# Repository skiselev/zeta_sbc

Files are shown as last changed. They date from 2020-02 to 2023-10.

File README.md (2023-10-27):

## Introduction

Zeta SBC V2 is a redesigned version of [Zeta SBC](http://www.malinov.com/Home/sergeys-projects/zeta-sbc). Compared to the first version this version features updated MMU with four banks, each one of those banks can be mapped to any 16 KiB page in 1 MiB on-board memory. It adds Z80 CTC which is used for generating periodic interrupts and as a vectored interrupt controller for UART and PPI. The FDC is replaced with 37C65. Compared to FDC9266 used in Zeta SBC it integrates input/output buffers and floppy disk control latch. Additionally 37C65 FDC is easier to obtain than FDC9266. And lastly it is made using CMOS technology and more power efficient than FDC9266

## Pictures

### Complete Board

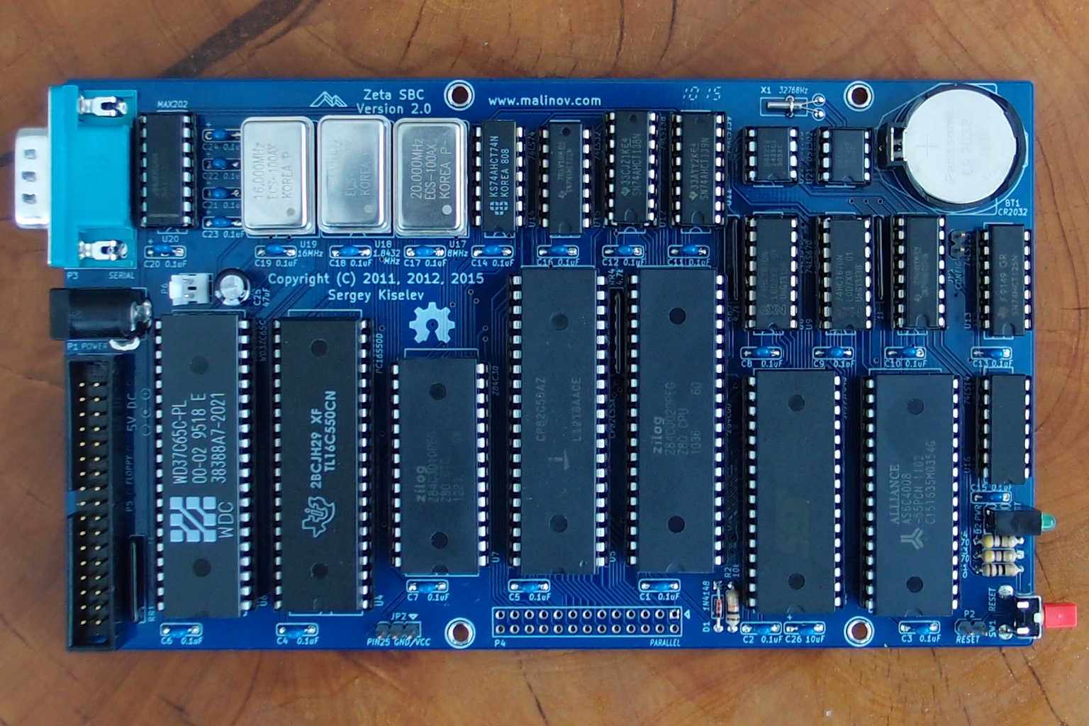
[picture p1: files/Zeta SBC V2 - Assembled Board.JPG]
Zeta SBC V2 - Assembled Board


### Zeta SBC with ParPortProp and a Floppy Drive

(FIXME: Picture shows Zeta SBC V1. Replace with Zeta SBC V2 when available.)
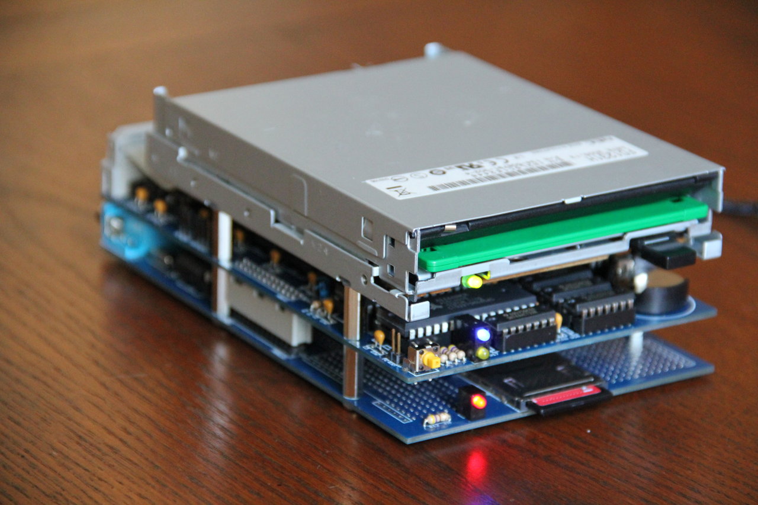
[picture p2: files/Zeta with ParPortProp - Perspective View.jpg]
Zeta SBC with ParPortProp


# Specifications

Zeta SBC V2 features following components:

* Z80 CPU
* 16550 UART - for connecting a console
* 8255 PPI - can be used for attaching a ParPortProp board, a hard drive using PPIDE or controlling some external devices
* Z80 CTC - can be used to generate periodic interrupts, and as an interrupt controller for UART and PPI
* Western Digital WD37C65, SMC FDC37C65, or GoldStar GM82C765B floppy disk controller.
* 512 KiB of battery backed SRAM
* 512 KiB of flash memory
* RTC

Zeta SBC V2 is compact and easy to build:

* Footprint of an 3.5" floppy drive (100 mm x 170.18 mm) and PCB can be mounted under a 3.5" drive.
* Uses only through hole components.
* Assumes using commonly available 3.5" floppy drives (not many people have 5.25" drives and even less 8" ones). Although it should work with 5.25" drives too.
* Only 2 configuration jumpers.
* Easy to use flash memory instead of UV EPROM.
* PCB mounted connectors, no need to build cables.
* Uses widely available components
* An easy way to get a "taste" of CP/M era computing.

# Hardware Documentation

File downloads are at the bottom of this page.

## KiCad Design Files

[Zeta SBC V2 - KiCad - 2.0.zip](files/Zeta%20SBC%20V2%20-%20KiCad%20-%202.0.zip)

## Schematic

[Zeta SBC V2 - Schematic - Color - 2.0.pdf](files/Zeta%20SBC%20V2%20-%20Schematic%20-%20Color%20-%202.0.pdf)

### PCB Version 2.0

[Zeta SBC V2 - Board - Color - 2.0.pdf](files/Zeta%20SBC%20V2%20-%20Board%20-%20Color%20-%202.0.pdf)

[Zeta SBC V2 - Gerber - 2.0.zip](files/Zeta%20SBC%20V2%20-%20Gerber%20-%202.0.zip)

## Input/Output Ports

* 20h - 23h (aliases 24h - 27h) - CTC Registers
  - 20h: Channel 0
  - 21h: Channel 1
  - 22h: Channel 2
  - 23h: Channel 3
  - See **Interrupts** section for Zeta SBC V2 specific CTC implementation and programming notes
* 28h (aliases 29h - 2Fh) - FDC CCR Register
  - Write only
  - FIXME: Add detailed description
* 30h (aliases 32h, 34h, 36h) - FDC Main Status Register
* 31h (aliases 33h, 35h, 37h) - FDC Data Register
* 38h (aliases 39h - 3Fh)
  - Write - FDC Diginal Output Register (DOR), also known as latch.
    + FIXME: Add detailed description
  - Read - Pulse FDC's /DACK and TC control lines
    + This port should be read following FDC data transfer command (read, write, format, etc.) to properly terminate data transfer.
* 60h-63h (alias 64h-67h) - PPI Registers
* 68h-6Fh - UART Registers
* 70h (aliases 71h-77h) - RTC Registers
  - Write:
    + Bits 0-3 - unused
    + Bit 4 - RTC Chip Enable
    + Bit 5 - RTC Write Enable
    + Bit 6 - RTC Clock
    + Bit 7 - RTC Input
  - Read:
    + Bit 0 - RTC Output
    + Bits 1-5 - unused
    + Bit 6 - Configuration Jumper (JP1)
    + Bit 7 - Disk Changed (DC) output from floppy drive. This can be used by the OS to detect floppy disk change. In such case CP/M should be warm rebooted.
* 78h-7Bh (alias 7Ch-7Fh) - Memory page select registers.
  - Write only
  - 78h - MPGSEL_0 - Page select register for bank #0 (0000h - 3FFFh)
  - 79h - MPGSEL_1 - Page select register for bank #1 (4000h - 7FFFh)
  - 7Ah - MPGSEL_2 - Page select register for bank #2 (8000h - 0BFFFh)
  - 7Bh - MPGSEL_3 - Page select register for bank #3 (0C000h - 0FFFFh)
  - Note: While these registers implemented as 8-bit registers, only 7 lower bits are decoded on board. 6 of these are actually used by on board memory, which contains of 64 pages, 16 KiB each.
* 7Ch (aliases 7Dh-7Fh) - MPGENA - Enable memory paging
  - Bits 0:
    + 0 = Disable memory paging (default after reset). When memory paging is disabled the memory page 0 (lower 16 KiB of the Flash ROM) is mapped to all banks.
    + 1 = Enable memory paging. Make sure that memory page select registers are configured properly before enabling paging.
  - Bits 1-7 - unused

## Memory

Zeta SBC V2 features a 512 KiB Flash ROM, and 512 KiB SRAM. The Flash ROM is used for the boot loader, monitor, OS (CP/M and ZSDOS at this point), and ROM disk. The SRAM is battery-backed, and is used for applications and for a RAM disk.

### Memory Banks and Paging

The 64 KiB Z80 memory address space is divided into four 16 KiB memory banks:

* Bank #0 (0000h - 3FFFh
* Bank #1 (4000h - 7FFFh)
* Bank #2 (8000h - 0BFFFh)
* Bank #3 (0C000h - 0FFFFh)

The physical memory (512 KiB Flash ROM and 512 KiB SRAM) is divided into 16 KiB pages:

* Pages 0 - 31 are mapped to the Flash ROM: page #0 starts at ROM address 00000h, and page #31 ends at ROM address 7FFFFh.
* Pages 32 - 63 are mapped to the SRAM: page #32 starts at RAM address 00000h, and page #63 ends at RAM address 7FFFFh.

Page select registers are used to map physical memory pages to the banks in Z80 address space:

* MPGSEL_0 (78h) - Page select register for bank #0
* M PGSEL_1 (79h) - Page select register for bank #1
* M PGSEL_2 (7Ah) - Page select register for bank #2
* M PGSEL_3 (7Bh) - Page select register for bank #3

Following a power on or a hard reset the memory paging mechanism is disabled, and memory address lines MA19 - MA14 are pulled down. So that page #0 (ROM addresses 00000h to 03FFF) is mapped to all four banks. That page should contain a boot loader that (among other things) configures and enables memory paging. Once page select registers are configured properly the memory paging can be enabled by setting bit 1 of MPGENA (7Ch) register.

### Programming Notes

1. The content of page select registers is unknown after a power on or a reboot. These registers need to be initialized before enabling memory paging. During the initialization the page select register for bank #0 needs to be set to page #0. So that CPU continues to execute instructions from that page.
2. The page select registers are implemented as 8-bit registers. Only 7 lower bits are decoded by Zeta SBC V2 memory chip select logic, and only 6 lower bits are actually used to address the memory. For future compatibility it is recommended that two higher bits of page select registers will be set to

## Interrupts

Zeta SBC V2 uses CTC as the source of vectored interrupts. For interrupts to function properly Z80 needs to be set to **interrupt mode 2**.

* Channels 0 and 1 are chained together. So that channel 1 can be used to generate low-frequency periodic interrupts:
  - Channel's 0 CLK/TG input is connected to UART_CLK/2 signal (921.6 kHz frequency)
  - Channel's 1 CLK/TG input in connected to c hannel's 0 ZC/TO output
* Channels 2 and 3 are connected to UART and FDC interrupt outputs. They can be used to generate vectored interrupts for these controllers:
  - Channel's 2 CLK/TG input is connected to UART interrupt output
  - Channel's 3 CLK/TG input is connected to 8255 PPI port PC3. This port is used as the interrupt output in PPI modes 1 and 2.

### Programming CTC to Generate Periodic Interrupts

CTC can generate periodic interrupts by dividing CTC clock (921.6 kHz) using channels 0 and 1 configured in counter mode. The CTC clock is connected to the trigger input of channel 0, and the ZC (zero count) output of channel 0 is connected the trigger input of channel 1. So that channel 0 will divide the clock, and the resulting signal will be divided further using channel 1.

In this example channel 0 is programmed with time constant of 256, so it will divide the input clock by 256, resulting in 3.6 kHz pulses. The channel 1 is programmed with down counter of 240, and will divide 3.6 kHz clock by 240, resulting in 15 Hz signal. That channel is also programmed to generate an interrupt every time counter reaches 0.

* Output `01000111 `to the channel 0. Configure the channel in the counter mode.
* Output `00000000&#xA0;`to the channel 0. Set the time constant to 256.
* Output `11000111 `to the channel 1. Configure the channel in the counter mode and enable interrupt when counter reaches 0.
* Output `11110000` to the channel 1. Set the time constant to 240, so that the interrupt will be generated every 1/15 of a second.
* Output `VVVVV000&#xA0;`to the channel 0. Set bits 7-3 of the interrupt vector. Bits 15-8 are set to the value of I register, bits 2 and 1 are set to the CTC channel number that caused the interrupt. Bit 0 is always 0. Note that each interrupt vector takes 2 bytes of memory and it should start on an even address.

### Programming CTC as an Interrupt Controller

CTC can be used as interrupt controller for UART and 8255 PPI using channels 2 and 3 respectively. In this case a CTC channel needs to be programmed for counter mode operation with time constant of 1. So that the first transition on CLK/TG input will result in counter going to 0 and CTC generating an interrupt.

* Output `110L0111` to the selected channel. This configures the channel in the counter mode with interrupts enabled. Bit 4 (L) sets the triggering edge: 0 - falling edge; 1 - rising edge.
* Output `00000001` to the selected channel. This loads value 1 to the time constant, so that an interrupt will be generated after detecting the first edge on the trigger input.
* Output `VVVVV000&#xA0;`to the channel 0. This sets bits 7-3 of the interrupt vector. Bits 15-8 are set to the I register, bits 2 and 1 are set to the CTC channel number that caused the interrupt. Bit 0 is always 0. Note that each interrupt vector takes 2 bytes of memory and it should start on an even address.

## Real Time Clock

Zeta SBC V2 includes a Maxim DS1302 RTC chip for timekeeping. It uses a CR2032 battery for power backup. The DS1302 has a 3-wire serial interface, and it is programmed through the RTC register (70h) using bit-banging. See Input/Output Ports section for the RTC register description. Please refer to [DS1302 datasheet](http://datasheets.maximintegrated.com/en/ds/DS1302.pdf) for programming information, and to the RomWBW (dsrtc.asm) for an RTC interface implementation.

## Jumpers and Connectors

### Jumper JP1 - CONFIG

JP1 is a software configuration jumper. It can be read by software using RTC port (70h) bit 6. This jumper is used by the RomWBW firmware with the ParPortProp support to configure the console device: it will use UART when this jumper is installed, and ParPortProp / VGA terminal when the jumper is not installed.

### Jumper JP2 - PIN25_GND/VCC

JP2 connects pin 25 of the parallel port P4 to either GND or Vcc (+5). Note that pin 1 is the pin that is closer to the parallel connector.

Warning: If JP2 is set incorrectly, it is possible to create a short circuit of the 5 Volt power supply.

| **Jumper Position** | **Description** |
| :--- | :--- |
| 1-2 | P4 pin 25 is connected to the ground |
| 2-3 | P4 pin 25 is connected to Vcc. Use this position with PPIDE, make sure to set jumper K1 on PPIDE to position 2-3. Please refer to [PPIDE documentation](https://sites.google.com/w/file/28373213/ppide-Install.txt) for more information. |
| **no jumper*** | P4 pin 25 is left open |

\* default

### Connector P1 - POWER

Connect regulated +5V power supply to this connector.

| Pin | Description |
| :-- | :--- |
| tip (the inner contact) | Positive terminal - +5V |
| barrel / sleeve | Negative terminal - ground |

### Connector P2 - RESET

P2 is a connector for an external reset button.

### Connector P3 - SERIAL

P3 is the serial port connector. It is normally used for connecting a console or terminal. P3 uses pinout similar to that of IBM AT serial port (with some signals missing). Use a null modem cable to connect to a PC.

| **Pin Number** | **Signal Name** | **Description and Notes** |
| :--- | :--- | :--- |
| 1 | DCD | Carrier Detect; Not used - Not connected on the SBC |
| **2** | **RX** | **Receive Data; Input to SBC** |
| **3** | **TX** | **Transmit Data; Output from SBC** |
| 4 | DTR | Data Terminal Ready;Not used - Not connected on the SBC |
| **5** | **Signal Ground** | **Connected to the SBC GND signal** |
| 6 | DSR | Data Set Ready;Not used - Not connected on the SBC |
| **7** | **RTS** | **Request to Send; Output from SBC** |
| **8** | **CTS** | **Clear to Send; Input to SBC** |
| 9 | RI | Ring Indicator;Not used - Not connected on the SBC |
| **Shield** | **DE9 Shield** | **Connected to the SBC GND signal** |

### Connector P4 - PARALLEL

P4 is the parallel port connector. It is connected directly to the 8255 PPI and can be used for attaching, a ParPortProp board, an IDE hard disk using the PPIDE mini board, or for controlling external devices (e.g. printer, watering system), or for extending the SBC (e.g. connecting an LCD display and a keyboard). The pinout of P4 is the same as in other N8VEM boards (SBC V1, SBC V2, SBC-188).

| **Pin Number** | **Description** | **Pin Number** | **Description** | **Pin Number** | **Description** | **Pin Number** | **Description** |
| :--- | :--- | :--- | :--- | :--- | :--- | :--- | :--- |
| 1 | PC0 | 9 | PC4 | 17 | PB7 | 25 | GND or VCC (see JP2) |
| 2 | PA0 | 10 | PA4 | 18 | PB0 | 26 | GND |
| 3 | PC1 | 11 | PC5 | 19 | PB6 |  |  |
| 4 | PA1 | 12 | PA5 | 20 | PB1 |  |  |
| 5 | PC2 | 13 | PC6 | 21 | PB5 |  |  |
| 6 | PA2 | 14 | PA6 | 22 | PB2 |  |  |
| 7 | PC3 | 15 | PC7 | 23 | PB4 |  |  |
| 8 | PA3 | 16 | PA7 | 24 | PB3 |  |  |

### Connector P5 - FLOPPY

P5 is the floppy interface connector. It uses PC compatible pinout. When using a PC floppy cable with a twist, Drive A (ID 0) is the drive after the twist and Drive B (ID 1) is the drive before the twist. When using only one FDD, either a twisted cable can be used, or the BIOS can be patched to use Drive B.

| **Pin Number** | **Description** | **Direction (relative to the SBC)** | **Connected to** |
| :--- | :--- | :--- | :--- |
| 1-33 | Odd pins are GND |  | GND |
| 2 | High Density. This signal is ignored by most (all?) 3.5" drives. | Output | DOR (bit 6) |
| 4, 6 | Not used |  | No connection |
| 8 | Index Pulse | Input | Schmidt Trigger, FDC (IDX) |
| 10 | Motor On B | Output | DOR (bit 1), Buffer |
| 12 | Drive Select A | Output | FDC (US0, US1), Decoder |
| 14 | Drive Select B | Output | FDC (US0, US1), Decoder |
| 16 | Motor On A | Output | DOR (bit 1), Buffer |
| 18 | Direction | Output | FDC (LCT/DIR), Multiplexer |
| 20 | Step | Output | FDC (FR/STEP), Multiplexer |
| 22 | Write Data | Output | FDC (WDOUT), OC Buffer |
| 24 | Write Enable | Output | FDC (WE), OC Buffer |
| 26 | Track Zero | Input | Multiplexer, FDC (FLT/TR0) |
| 28 | Write Protect | Input | Multiplexer, FDC (WP/TS) |
| 30 | Read Data | Input | Schmidt Trigger, FDC (~DSKD) |
| 32 | Select Head | Output | FDC (HD), OC Buffer |
| 34 | Disk Changed | Input | DIR (bit 0) |

### Connector P6 - 5V

P6 is the 5V power output for the floppy drive. Alternatively it can be used instead of P1 for supplying power to the board. It is recommended to use a polarized header for P6 to avoid incorrect power polarity which probably will destroy FDD or components on the SBC board.

| **Pin Number** | **Description** |
| :--- | :--- |
| 1 | 5V |
| 2 | GND |

**Warning P6 connector's key is reversed compared to Zeta SBC V 1.x. Please pay attention when upgrading from older boards. The polarity marking on the silkscreen is correct.**

## Bill of Materials (BOM)

### BOM Notes

Disclaimer: I did my best to make sure that components listed in this BOM will be compatible with Zeta SBC V2. Obviously I didn't order all of components listed here, and I was not able to actually verify that they will work. Please make sure to double check specifications on manufacturer's and seller's web site before ordering. Please let me know if you found any problems or incompatibilities.

Many components have multiple part numbers listed in BOM. There are some differences between various part numbers, such as:

* Different manufacturer. For example Texas Instruments vs. National Semiconductor for IC. Usually ICs built using the same technology will be 100% compatible. For some other components, for example connectors, sockets, or capacitors, it could be some difference in the quality. It is likely to get a better quality connector from TE (was AMP/Tyco) than from some obscure manufacturer (e.g. components sold under Jameco ValuePro brand).
* Specification differences
  - IC built using different different technologies (CMOS, TTL, NMOS) will have different specifications, and you might prefer to use certain IC family.
  - Difference in IC frequency or speed rating, especially for CPU, PPI, and memory.
  - Mechanical differences, especially for switches. Pick whatever suits best in your enclosure.
  - Some other minor differences. For example: RoHS or Pb-free vs. regular components; thickness of gold plating on connectors; frequency stability of oscillators and crystals.
* Price differences
  - For some reason some components are priced much higher than other otherwise similar parts.
  - One extreme example would be 512 KiB SRAM chips sold by Jameco (157358 and 242448) for almost $19 each, while AS6C4008-55PCN part sold by Mouser costs less than $5.
  - Some eBay sellers ask premium price for components because of their perceived uniqueness (keywords: vintage, rare, NOS, collectible), or special packaging (e.g. pink ceramic vs. plastic, gold plating).

If unsure what to order, read specifications on seller's and manufacturer's web sites. Also please read Replacement Notes below. Finally, consult people on [N8VEM news group](http://groups.google.com/group/n8vem).

## BOM

| **Component type** | **Reference** | **Description** | **Quantity** | **Possible sources and notes** |
| :--- | :--- | :--- | :--- | :--- |
| PCB |  | Zeta SBC V2 PCB Version 2.0 | 1 | Order from Sergey |
| Battery Holder | BT1 | CR2032 batter holder, 20 mm lead spacing | 1 | Mouser [122-2420-GR](http://www.mouser.com/ProductDetail/Eagle-Plastic-Devices/122-2420-GR/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 "Click to view additional information on this product."),[122-2620-GR](http://www.mouser.com/ProductDetail/Eagle-Plastic-Devices/122-2620-GR/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 "Click to view additional information on this product.");Jameco [355434](http://www.jameco.com/webapp/wcs/stores/servlet/Product_10001_10001_355434_-1) |
| Capacitor | C1 - C24 | 0.1 uF ceramic, 5.08 mm lead spacing | 24 | Mouser [810-FK28X7R1H104K](http://www.mouser.com/search/refine.aspx?Keyword=810-FK28X7R1H104K),[80-C323C104K5R](http://www.mouser.com/ProductDetail/Kemet/C323C104K5R5TA/?qs=sGAEpiMZZMuAYrNc52CMZJc2YQhHPlYVWR1uyzMGvKQ%3D); Jameco [25523](http://www.jameco.com/webapp/wcs/stores/servlet/Product_10001_10001_25523_-1) |
| Capacitor | C25 | 47 uF, 6.3 V electrolytic | 1 | Mouser [667-ECA-1HHG470](http://www.mouser.com/ProductDetail/Panasonic-Electronic-Components/ECA-1HHG470/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 "Click to view additional information on this product.");Jameco [31114](http://www.jameco.com/webapp/wcs/stores/servlet/Product_10001_10001_31114_-1) |
| Capacitor | C26 | 10 uF ceramic, 5.08 mm lead spacing | 1 | Mouser [810-FK24X5R1C106K](http://www.mouser.com/search/refine.aspx?Keyword=810-FK24X5R1C106K) Note: Can be replaced with tantalum or electrolytic capacitors |
| Diode | D1 | 1N4148 | 1 | Mouser [512-1N4148](http://www.mouser.com/ProductDetail/Fairchild-Semiconductor/1N4148/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 "Click to view additional information on this product."),[771-1N4148-T/R](http://www.mouser.com/ProductDetail/NXP-Semiconductors/1N4148113/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 "Click to view additional information on this product.");Jameco [36038](http://www.jameco.com/webapp/wcs/stores/servlet/Product_10001_10001_36038_-1),[179215](http://www.jameco.com/webapp/wcs/stores/servlet/Product_10001_10001_179215_-1) |
| Diode | D2, D3 | Bi-level LED indicator | 1 | Mouser [696-SSF-LXH240GYD](http://www.mouser.com/ProductDetail/Lumex/SSF-LXH240GYD/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 "Click to view additional information on this product."); Jameco: Search for uni-color bi-level LED |
| Standoff | HOLE1, HOLE2, HOLE3, HOLE4 | Standoff, M3 male / female, 20 mm | 4 | Mouser [534-24317](http://www.mouser.com/ProductDetail/Keystone-Electronics/24317/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 "Click to view additional information on this product."),[534-25505](http://www.mouser.com/ProductDetail/Keystone-Electronics/25505/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 "Click to view additional information on this product."),[855-R30-3012002](http://www.mouser.com/ProductDetail/Harwin/R30-3012002/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 "Click to view additional information on this product.") Note: The length of male end of these standoffs is 8 mm. It is too long for some floppy disk drives (you'll notice that standoff doesn't go completely inside the floppy drive mount hole). In this case cut a few millimeters using a file or a fine saw. |
| Screw | HOLE1, HOLE2, HOLE3, HOLE4 | Screw, M3, 6 mm | 4 | Use regular 3 mm floppy or CD-ROM drive mounting screws. Mouser [534-29311](http://www.mouser.com/ProductDetail/Keystone-Electronics/29311/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) |
| Connector | JP1, P2 | 2x1 pin header | 2 | Mouser [649-78229-102HLF](http://www.mouser.com/ProductDetail/FCI/78229-102HLF/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 "Click to view additional information on this product.");Jameco [108338](http://www.jameco.com/webapp/wcs/stores/servlet/Product_10001_10001_108338_-1) |
| Connector | JP2 | 3x1 pin header | 1 | Mouser [649-69190-103HLF](http://www.mouser.com/ProductDetail/FCI/69190-103HLF/?qs=sGAEpiMZZMvlX3nhDDO4AIYfP1TbgJhjYISz3bCP%2Fwo%3D "Click to view additional information on this product."),[649-78229-103HLF](http://www.mouser.com/ProductDetail/FCI/78229-103HLF/?qs=sGAEpiMZZMtsLRyDR9nM14Vjyw4ze%252bjtWzL%2FZN0BySE%3D "Click to view additional information on this product.");Jameco [109576](http://www.jameco.com/webapp/wcs/stores/servlet/Product_10001_10001_109576_-1) |
| Connector | P1 | DC jack | 1 | Mouser [806-KLDX-0202-A](http://www.mouser.com/ProductDetail/Kycon/KLDX-0202-A/?qs=sGAEpiMZZMu2f9RNbWupYrp4fVeNia8SgJaG%252bI5Hr1k%3D "Click to view additional information on this product.");Jameco [101178](http://www.jameco.com/webapp/wcs/stores/servlet/Product_10001_10001_101178_-1) |
| Connector | P3 | DE9M, right angle PCB mount | 1 | Mouser [806-K22X-E9P-N](http://www.mouser.com/ProductDetail/Kycon/K22X-E9P-N/?qs=sGAEpiMZZMu857ZbtCGHt0PbUrjjd%2FNBm0naypBlx9c%3D "Click to view additional information on this product."),[806-K22X-E9P-N-99](http://www.mouser.com/ProductDetail/Kycon/K22X-E9P-N-99/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 "Click to view additional information on this product.") (teal color),[571-7478404](http://www.mouser.com/ProductDetail/TE-Connectivity-AMP/747840-4/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 "Click to view additional information on this product.");Jameco [104943](http://www.jameco.com/webapp/wcs/stores/servlet/Product_10001_10001_104943_-1),[614459](http://www.jameco.com/webapp/wcs/stores/servlet/Product_10001_10001_614459_-1),[614432](http://www.jameco.com/webapp/wcs/stores/servlet/Product_10001_10001_614432_-1); |
| Connector | P4 | 13x2 pin header | 1 | Mouser [649-68602-126HLF](http://www.mouser.com/ProductDetail/FCI/68602-126HLF/?qs=sGAEpiMZZMtsLRyDR9nM1%252bmbmmVUI0dAYWKlImNZbew%3D),[649-77313-824-26LF](http://www.mouser.com/ProductDetail/FCI/77313-824-26LF/?qs=sGAEpiMZZMtsLRyDR9nM14Vjyw4ze%252bjtilYVPfgiHws%3D);Jameco [53495](http://www.jameco.com/webapp/wcs/stores/servlet/Product_10001_10001_53495_-1) Note: don't use shrouded connector, as it will interfere with the standoff and other components. |
| Connector | P5 | 17x2 pin header shrouded | 1 | Mouser [517-30334-6002](http://www.mouser.com/ProductDetail/3M-Electronic-Solutions-Division/30334-6002HB/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 "Click to view additional information on this product."),[571-1033087](http://www.mouser.com/ProductDetail/TE-Connectivity/103308-7/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 "Click to view additional information on this product."),[571-5103308-7](http://www.mouser.com/ProductDetail/TE-Connectivity/5103308-7/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 "Click to view additional information on this product.");Jameco [68583](http://www.jameco.com/webapp/wcs/stores/servlet/Product_10001_10001_68583_-1),[753547](http://www.jameco.com/webapp/wcs/stores/servlet/Product_10001_10001_753547_-1) |
| Connector | P6 | 2 pin header with friction lock | 1 | Mouser [571-6404562](http://www.mouser.com/ProductDetail/TE-Connectivity-AMP/640456-2/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),[571-3-641126-2](http://www.mouser.com/ProductDetail/TE-Connectivity-AMP/3-641126-2/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),[571-3-641215-2](http://www.mouser.com/ProductDetail/TE-Connectivity-AMP/3-641215-2/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);Jameco [232266](http://www.jameco.com/webapp/wcs/stores/servlet/Product_10001_10001_232266_-1),[613931](http://www.jameco.com/webapp/wcs/stores/servlet/Product_10001_10001_613931_-1); Corresponding female connector: Mouser [571-770602-2](http://www.mouser.com/ProductDetail/TE-Connectivity-AMP/770602-2/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);Jameco [234798](http://www.jameco.com/webapp/wcs/stores/servlet/Product_10001_10001_234798_-1)Contacts (2 contacts needed):Mouser [571-770666-1](http://www.mouser.com/ProductDetail/TE-Connectivity-AMP/770666-1/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);Jameco [234923](http://www.jameco.com/webapp/wcs/stores/servlet/Product_10001_10001_234923_-1),[736501](http://www.jameco.com/webapp/wcs/stores/servlet/Product_10001_10001_736501_-1); It is recommended to use a polarized header to avoid incorrect power polarity. |
| Resistor | R1 | 10 Ohm, 1/4 W | 1 | Mouser [291-10-RC](http://www.mouser.com/ProductDetail/Xicon/291-10-RC/?qs=sGAEpiMZZMu61qfTUdNhG5WVxMYmJR0O1OUR1xbHmxs%3D);Jameco [690380](http://www.jameco.com/webapp/wcs/stores/servlet/Product_10001_10001_690380_-1) |
| Resistor | R2 | 10 kOhm, 1/4 W | 1 | Mouser [291-10K-RC](http://www.mouser.com/ProductDetail/Xicon/291-10K-RC/?qs=sGAEpiMZZMu61qfTUdNhG6xwTrVwTvbz8PPav3aExs8%3D); Jameco [691104](http://www.jameco.com/webapp/wcs/stores/servlet/Product_10001_10001_691104_-1) |
| Resistor | R3, R4 | 470 Ohm, 1/4 W | 2 | Mouser [291-470-RC](http://www.mouser.com/ProductDetail/Xicon/291-470-RC/?qs=sGAEpiMZZMu61qfTUdNhG1AdbDi3ermZfsjMZ8nKiDY%3D); Jameco [690785](http://www.jameco.com/webapp/wcs/stores/servlet/Product_10001_10001_690785_-1) |
| Resistor Array | RR1, RR2 | 1 kOhm, 6 pin, bussed resistor array | 2 | Mouser [264-1.0K-RC](http://www.mouser.com/ProductDetail/Xicon/264-10K-RC/?qs=sGAEpiMZZMvrmc6UYKmaNQbJ%252b29QTxaEngMB%2FdVaAdM%3D "Click to view additional information on this product."),[652-4306R-1LF-1K](http://www.mouser.com/ProductDetail/Bourns/4306R-101-102LF/?qs=sGAEpiMZZMvrmc6UYKmaNTNUNwWuH088chgRi4yNveI%3D "Click to view additional information on this product.") Note: When using CMOS U11, RR2 can have a higher value, for example 4.7k. This will reduce the power consumption. |
| Resistor Array | RR3, RR4 | 4.7 kOhm, 6 pin, bussed resistor array | 2 | Mouser [264-4.7K-RC](http://www.mouser.com/ProductDetail/Xicon/264-47K-RC/?qs=sGAEpiMZZMvrmc6UYKmaNVNDE5UWkgN%2FsgYW0PIGqes%3D "Click to view additional information on this product."),[652-4306R-1LF-4.7K](http://www.mouser.com/ProductDetail/Bourns/4306R-101-472LF/?qs=sGAEpiMZZMvrmc6UYKmaNWgIZ6biHU4EEgaZTof5r6w%3D "Click to view additional information on this product.") |
| Switch | SW1 | Tactile switch, right angle | 1 | Mouser [653-B3F-3100](http://www.mouser.com/ProductDetail/Omron-Electronics/B3F-3100/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 "Click to view additional information on this product."),[653-B3F-3152](http://www.mouser.com/ProductDetail/Omron-Electronics/B3F-3152/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 "Click to view additional information on this product."),[706-95C06A2RAT](http://www.mouser.com/ProductDetail/Grayhill/95C06A2RAT/?qs=sGAEpiMZZMsgGjVA3toVBGztKQtvElzogNtUxy25yuk%3d "Click to view additional information on this product."),[706-95C06C2RAT](http://www.mouser.com/ProductDetail/Grayhill/95C06C2RAT/?qs=sGAEpiMZZMsgGjVA3toVBGztKQtvElzoxqE4Q1H5TNc%3d "Click to view additional information on this product."),[706-95C06F2RAT](http://www.mouser.com/ProductDetail/Grayhill/95C06F2RAT/?qs=sGAEpiMZZMsgGjVA3toVBGztKQtvElzoEUXifV0kpgg%3d "Click to view additional information on this product.")Note: Switches can have different actuator length. You might want to select the switch according your own preferences, for example the enclosure type you want to use, and whatever you want the reset button to stick out of the enclosure or to stay hidden inside. Jameco [1953575](http://www.jameco.com/webapp/wcs/stores/servlet/Product_10001_10001_1953575_-1) |
| IC | U1 | Z80 CPU, CMOS, 40 pin DIP - Z84C00xxPEG | 1 | Mouser [692-Z84C0010PEG](http://www.mouser.com/ProductDetail/ZiLOG/Z84C0010PEG/?qs=sGAEpiMZZMvu0Nwh4cA1wSoSQ2enekUq2IMsKtAiEbo%3D),[692-Z84C0008PEG](http://www.mouser.com/ProductDetail/ZiLOG/Z84C0008PEG/?qs=sGAEpiMZZMvu0Nwh4cA1wWtRoPcQBaz3A%252bL%2FQ9ovAB8%3D); Jameco [35705](http://www.jameco.com/webapp/wcs/stores/servlet/Product_10001_10001_35705_-1),[35781](http://www.jameco.com/webapp/wcs/stores/servlet/Product_10001_10001_35781_-135781) Frequency of U17 (CPU clock) oscillator should be less or equal to CPU frequency. 8MHz CPU recommended for 1.44 MB floppy disks support. |
| IC | U2 | 512 KiB flash, 32 pin DIP - 39SF040,29F040, 29C040 | 1 | Mouser [804-39SF0407CPHE](http://www.mouser.com/ProductDetail/Microchip-Technology/SST39SF040-70-4C-PHE/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 "Click to view additional information on this product."); Jameco [242667](http://www.jameco.com/webapp/wcs/stores/servlet/Product_10001_10001_242667_-1) |
| IC | U3 | 512 KiB SRAM, 32 pin DIP -AS6C4008-55PCN | 1 | Mouser [913-AS6C4008-55PCN](http://www.mouser.com/ProductDetail/Alliance-Memory/AS6C4008-55PCN/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) Note: Jameco 242448 and 157358 (BS62LV4006P) should work too, but they are way too expensive |
| IC | U4 | 16550 UART | 1 | Mouser [926-PC16550DN/NOPB](http://www.mouser.com/ProductDetail/Texas-Instruments/PC16550DN-NOPB/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); Jameco [288809](http://www.jameco.com/webapp/wcs/stores/servlet/Product_10001_10001_288809_-1) |
| IC | U5 | 8255 PPI | 1 | Mouser [968-CP82C55AZ](http://www.mouser.com/ProductDetail/Intersil/CP82C55AZ/?qs=cbl4%252bYHJGOF3%2FjEgaAvGRe5K%2FILMXjQ3),[968-CP82C55A](http://www.mouser.com/ProductDetail/Intersil/CP82C55A/?qs=B4b5rvZIvWUoKcRPBZOAqTe8YvZ7Q5In); Jameco [52417](http://www.jameco.com/webapp/wcs/stores/servlet/Product_10001_10001_52417_-1) Unicorn Electronics (order 82C55) |
| IC | U6 | FDC, 40 pin DIP WD37C65, FDC37C65, GM82C765 | 1 | Buy from eBay |
| IC | U7 | Z80 CTC, CMOS, 28 pin DIP -Z84C30xxPEG | 1 | Mouser [692-Z84C3010PEG](http://www.mouser.com/ProductDetail/ZiLOG/Z84C3010PEG/?qs=sGAEpiMZZMtp5ziQ9mm%252bAlDnLybnUSNF),[692-Z84C3008PEG](http://www.mouser.com/ProductDetail/ZiLOG/Z84C3008PEG/?qs=sGAEpiMZZMsn4IaorHFpML59rb7vgZ39); Jameco [35609](http://www.jameco.com/webapp/wcs/stores/servlet/Product_10001_10001_35609_-1) |
| IC | U8, U9 | 74LS670 | 2 | Mouser [595-SN74LS670N](http://www.mouser.com/search/refine.aspx?Keyword=595-SN74LS670N),[771-HCT670N652](http://www.mouser.com/search/refine.aspx?Keyword=771-HCT670N652); Jameco [47976](http://www.jameco.com/webapp/wcs/stores/servlet/Product_10001_10001_47976_-1) Unicorn Electronics 74LS670 |
| IC | U10 | 74LS174 | 1 | Mouser [595-SN74ALS174N](http://www.mouser.com/ProductDetail/Texas-Instruments/SN74ALS174N/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),[595-SN74LS174N](http://www.mouser.com/ProductDetail/Texas-Instruments/SN74LS174N/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),[595-SN74AHCT174N](http://www.mouser.com/ProductDetail/Texas-Instruments/SN74AHCT174N/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); Unicorn Electronics; Jameco [46931](http://www.jameco.com/webapp/wcs/stores/servlet/Product_10001_10001_46931_-1) |
| IC | U11 | 74ALS139 | 1 | Mouser [595-SN74ALS139N](http://www.mouser.com/ProductDetail/Texas-Instruments/SN74ALS139N/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),[595-SN74LS139AN](http://www.mouser.com/ProductDetail/Texas-Instruments/SN74LS139AN/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),[595-CD74ACT139E](http://www.mouser.com/ProductDetail/Texas-Instruments/CD74ACT139E/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),[595-SN74AHCT139N](http://www.mouser.com/ProductDetail/Texas-Instruments/SN74AHCT139N/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); Unicorn Electronics; Jameco [46623](http://www.jameco.com/webapp/wcs/stores/servlet/Product_10001_10001_46623_-1),[301268](http://www.jameco.com/webapp/wcs/stores/servlet/Product_10001_10001_301268_-1) |
| IC | U12 | 74LS138 | 1 | Mouser [595-SN74ALS138AN](http://www.mouser.com/ProductDetail/Texas-Instruments/SN74ALS138AN/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),[595-SN74LS138N](http://www.mouser.com/ProductDetail/Texas-Instruments/SN74LS138N/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),[595-SN74AHCT138N](http://www.mouser.com/ProductDetail/Texas-Instruments/SN74AHCT138N/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); Unicorn Electronics; Jameco [46607](http://www.jameco.com/webapp/wcs/stores/servlet/Product_10001_10001_46607_-1),[301233](http://www.jameco.com/webapp/wcs/stores/servlet/Product_10001_10001_301233_-1),[44927](http://www.jameco.com/webapp/wcs/stores/servlet/Product_10001_10001_44927_-1) |
| IC | U13 | 74LS125 | 1 | Mouser [595-SN74LS125AN](http://www.mouser.com/ProductDetail/Texas-Instruments/SN74LS125AN/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),[595-SN74AHCT125N](http://www.mouser.com/ProductDetail/Texas-Instruments/SN74AHCT125N/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); Unicorn Electronics; Jameco [46501](http://www.jameco.com/webapp/wcs/stores/servlet/Product_10001_10001_46501_-1) |
| IC | U14 | 74LS74 | 1 | Mouser [595-SN74ALS74AN](http://www.mouser.com/ProductDetail/Texas-Instruments/SN74ALS74AN/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),[595-SN74AHCT74N](http://www.mouser.com/search/refine.aspx?Keyword=595-SN74AHCT74N); Jameco [48004](http://www.jameco.com/webapp/wcs/stores/servlet/Product_10001_10001_48004_-1),[295726](http://www.jameco.com/webapp/wcs/stores/servlet/Product_10001_10001_295726_-1),[45137](http://www.jameco.com/webapp/wcs/stores/servlet/Product_10001_10001_45137_-1) Unicorn Electronics 74ALS74, 74AHCT74 |
| IC | U15 | 74LS32 | 1 | Mouser [595-SN74ALS32N](http://www.mouser.com/ProductDetail/Texas-Instruments/SN74ALS32N/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),[595-SN74LS32N](http://www.mouser.com/ProductDetail/Texas-Instruments/SN74LS32N/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),[595-SN74ACT32N](http://www.mouser.com/ProductDetail/Texas-Instruments/SN74ACT32N/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),[595-CD74ACT32E](http://www.mouser.com/ProductDetail/Texas-Instruments/CD74ACT32E/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); Unicorn Electronics; Jameco [47466](http://www.jameco.com/webapp/wcs/stores/servlet/Product_10001_10001_47466_-1),[295515](http://www.jameco.com/webapp/wcs/stores/servlet/Product_10001_10001_295515_-1) |
| IC | U16 | 74LS14 | 1 | Mouser [595-SN74LS14N](http://www.mouser.com/ProductDetail/Texas-Instruments/SN74LS14N/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),[595-SN74AHCT14N](http://www.mouser.com/ProductDetail/Texas-Instruments/SN74AHCT14N/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); Unicorn Electronics; Jameco [46640](http://www.jameco.com/webapp/wcs/stores/servlet/Product_10001_10001_46640_-1),[295460](http://www.jameco.com/webapp/wcs/stores/servlet/Product_10001_10001_295460_-1),[44935](http://www.jameco.com/webapp/wcs/stores/servlet/Product_10001_10001_44935_-1) |
| IC | U17 | CPU clock oscillator, full can | 1 | See frequency selection note for U1. 4 MHz: Mouser [815-ACO-4-EK](http://www.mouser.com/ProductDetail/ABRACON/ACO-4000MHZ-EK/?qs=sGAEpiMZZMt8zWNA7msRCufK6FojpZgBkZbpC3y2DKw%3D),[520-TCF400-X](http://www.mouser.com/ProductDetail/ECS/ECS-100AX-40/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);Jameco [27967](http://www.jameco.com/webapp/wcs/stores/servlet/Product_10001_10001_27967_-1) 6 MHz: Mouser [520-TCF600-X](http://www.mouser.com/ProductDetail/ECS/ECS-100AX-60/?qs=sGAEpiMZZMt8zWNA7msRCkZF6o3VgKlSVVceCglATlo%3D) 8 MHz: Mouser [815-ACO-8-EK](http://www.mouser.com/ProductDetail/ABRACON/ACO-8000MHZ-EK/?qs=sGAEpiMZZMt8zWNA7msRCufK6FojpZgBol2LWy2yIwI%3D),[520-TCF800-X](http://www.mouser.com/ProductDetail/ECS/ECS-100AX-80/?qs=sGAEpiMZZMt8zWNA7msRCkZF6o3VgKlSdZ7QUqFOCa0%3D);Jameco [27991](http://www.jameco.com/webapp/wcs/stores/servlet/Product_10001_10001_27991_-1) 10 MHz: Mouser [815-ACO-10-EK](http://www.mouser.com/ProductDetail/ABRACON/ACO-10000MHZ-EK/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),[520-TCF1000-X](http://www.mouser.com/ProductDetail/ECS/ECS-100AX-100/?qs=sGAEpiMZZMt8zWNA7msRCkZF6o3VgKlSWiBx3iH%252buXU%3D);Jameco [27887](http://www.jameco.com/webapp/wcs/stores/servlet/Product_10001_10001_27887_-1) 20 MHz: Mouser [815-ACO-20-EK](http://www.mouser.com/ProductDetail/ABRACON/ACO-20000MHZ-EK/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),[520-TCF2000-X](http://www.mouser.com/ProductDetail/ECS/ECS-100AX-200/?qs=sGAEpiMZZMt8zWNA7msRCkZF6o3VgKlSDgSisz37dM4%3D);Jameco [27932](http://www.jameco.com/webapp/wcs/stores/servlet/Product_10001_10001_27932_-1) |
| IC | U18 | 1.8432 MHz oscillator, full can | 1 | Mouser [520-TCF184-X](http://www.mouser.com/ProductDetail/ECS/ECS-100AX-18432/?qs=sGAEpiMZZMt8zWNA7msRCkZF6o3VgKlSBPpGLyq2pks%3D); Jameco [27879](http://www.jameco.com/webapp/wcs/stores/servlet/Product_10001_10001_27879_-1) |
| IC | U19 | 16 MHz oscillator, full can | 1 | Mouser [520-TCF1600-X](http://www.mouser.com/ProductDetail/ECS/ECS-100AX-160/?qs=sGAEpiMZZMt8zWNA7msRCkZF6o3VgKlScoRySUymIsQ%3d),[815-ACO-16-EK](http://www.mouser.com/ProductDetail/ABRACON/ACO-16000MHZ-EK/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) |
| IC | U20 | MAX202 | 1 | Mouser [595-TRS202ECN](http://www.mouser.com/ProductDetail/Texas-Instruments/TRS202ECN/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),[701-SP202ECP-L](http://www.mouser.com/ProductDetail/Exar/SP202ECP-L/?qs=sGAEpiMZZMtnIqnDeWcRHSgmUQC5j8NkoHNGApCEA9Y%3D),[700-MAX202CPE](http://www.mouser.com/ProductDetail/Maxim-Integrated-Products/MAX202CPE+/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),[700-MAX232ACP](http://www.mouser.com/ProductDetail/Maxim-Integrated-Products/MAX232ACPE+/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); Jameco [1800552](http://www.jameco.com/webapp/wcs/stores/servlet/Product_10001_10001_1800552_-1),[142535](http://www.jameco.com/webapp/wcs/stores/servlet/Product_10001_10001_142535_-1) |
| IC | U21 | DS1302 | 1 | Mouser [700-DS1302](http://www.mouser.com/ProductDetail/Maxim-Integrated-Products/DS1302+/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),[700-DS1302N](http://www.mouser.com/ProductDetail/Maxim-Integrated-Products/DS1302N+/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); Jameco [176778](http://www.jameco.com/webapp/wcs/stores/servlet/Product_10001_10001_176778_-1),[780481](http://www.jameco.com/webapp/wcs/stores/servlet/Product_10001_10001_780481_-1) |
| IC | U22 | DS1210 | 1 | Mouser [700-DS1210](http://www.mouser.com/ProductDetail/Maxim-Integrated-Products/DS1210+/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); Jameco [114198](http://www.jameco.com/webapp/wcs/stores/servlet/Product_10001_10001_114198_-1) |
| IC Socket | U1, U4 - U6 | 40 pin 600 mil DIP socket | 4 | Mouser [517-4840-6000-CP](http://www.mouser.com/ProductDetail/3M-Electronic-Solutions-Division/4840-6000-CP/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),[649-DILB40P223TLF](http://www.mouser.com/ProductDetail/FCI/DILB40P-223TLF/?qs=sGAEpiMZZMs%2FSh%2Fkjph1tnWBa37eU7kEvItX7WAak1Y%3D);Jameco [41111](http://www.jameco.com/webapp/wcs/stores/servlet/Product_10001_10001_41111_-1) |
| IC Socket | U2, U3 | 32 pin 600 mil DIP socket | 2 | Mouser [517-4832-6000-CP](http://www.mouser.com/ProductDetail/3M-Electronic-Solutions-Division/4832-6000-CP/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),[649-DILB32P223TL](http://www.mouser.com/ProductDetail/FCI/DILB32P223TLF/?qs=sGAEpiMZZMs%2FSh%2Fkjph1tuCWXqks4O6emg1jqvuxPfs%3D);Jameco [112301](http://www.jameco.com/webapp/wcs/stores/servlet/Product_10001_10001_112301_-1) |
| IC Socket | U7 | 28 pin 600 mil DIP socket | 1 | Mouser [517-4828-6000-CP](http://www.mouser.com/ProductDetail/3M-Electronic-Solutions-Division/4828-6000-CP/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),[649-DILB28P223TLF](http://www.mouser.com/ProductDetail/FCI/DILB28P-223TLF/?qs=sGAEpiMZZMs%2FSh%2Fkjph1tnWBa37eU7kELM2y4cpXfjk%3D) |
| IC Socket | U8 - U12, U24 | 16 pin 300 mil DIP socket | 6 | Mouser [517-4816-3000-CP](http://www.mouser.com/ProductDetail/3M-Electronic-Solutions-Division/4816-3000-CP/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),[649-DILB16P-223TLF](http://www.mouser.com/ProductDetail/FCI/DILB16P-223TLF/?qs=sGAEpiMZZMs%2FSh%2Fkjph1tnWBa37eU7kEZ8uy8DVlop0%3D);Jameco [37373](http://www.jameco.com/webapp/wcs/stores/servlet/Product_10001_10001_37373_-1) |
| IC Socket | U13 - U16 | 14 pin 300 mil DIP socket | 4 | Mouser [517-4814-3000-CP](http://www.mouser.com/ProductDetail/3M-Electronic-Solutions-Division/4814-3000-CP/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),[649-DILB14P-223TLF](http://www.mouser.com/ProductDetail/FCI/DILB14P-223TLF/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);Jameco [37162](http://www.jameco.com/webapp/wcs/stores/servlet/Product_10001_10001_37162_-1) |
| IC Socket | U21, U22 | 8 pin 300 mil DIP socket | 2 | Mouser [517-4808-3000-CP](http://www.mouser.com/ProductDetail/3M-Electronic-Solutions-Division/4808-3000-CP/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),[649-DILB8P223TLF](http://www.mouser.com/ProductDetail/FCI/DILB8P-223TLF/?qs=sGAEpiMZZMs%2FSh%2Fkjph1trsk3O0a2elqycTEeDCVfAg%3D);Jameco [51571](http://www.jameco.com/webapp/wcs/stores/servlet/Product_10001_10001_51571_-1) |
| Oscillator Socket | U17 - U19 | 4 pin 300 mil DIP full can oscillator socket | 3 | Mouser [535-1107741](http://www.mouser.com/ProductDetail/Aries/1107741/?qs=sGAEpiMZZMs%2FSh%2Fkjph1tvt1%2FmEPT%2FXoVZs6QxzSzII%3D);Jameco [133006](http://www.jameco.com/webapp/wcs/stores/servlet/Product_10001_10001_133006_-1) |
| Crystal | X1 | 32768 Hz crystal | 1 | Mouser [695-CFS206-327KB-U](http://www.mouser.com/ProductDetail/Citizen/CFS206-32768KDZB-UB/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),[520-ECS327-6-13-X](http://www.mouser.com/ProductDetail/ECS/ECS-327-6-13X/?qs=sGAEpiMZZMsBj6bBr9Q9aWDZfF25lWfigWLFR7cXhrY%3d),[628-VT200F-6PF20PPM](http://www.mouser.com/ProductDetail/Seiko-Semiconductors/VT200F-6PF20PPM/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);Jameco [14584](http://www.jameco.com/webapp/wcs/stores/servlet/Product_10001_10001_14584_-1) |

### Replacement Notes

* 74xx logic
  - TTL logic families: 74LS, 74ALS, 74F, or TTL-compatible CMOS: 74HCT, 74AHCT, and 74ACT could be used.
  - Plain 74LS should work with CPU frequency up to 8 MHz. But it is recommended to use higher speed and lower power 74ALS ICs.
  - (FIXME: NOT TESTED YET) Tested with 74LS, 74ALS and 74HCT / 74AHCT logic families. Works on frequency up to 20MHz.
* Z80 CPU, Z80 CTC
  - Either NMOS or CMOS parts work. It is recommended to use at least 4 MHz CPU. 6 MHz or faster CPU is required for 1.44MB disk support. 8 MHz is recommended.
  - CMOS versions - Z84C00xxPEG or Z84C00xxPEC, and Z84C30xxPEG or Z84C30xxPEC are recommended.
  - Note: PEG or PEC suffixes mean 40 pin plastic DIP package, PEG is RoHS compliant, PEC is not.
  - Tested with CMOS Z84C00 (6MHz, 8MHz, 20MHz) and NMOS Z8400 (4MHz) CPUs, and CMOS Z84C0010PEG CTC
* 16550 UART
  - 16550 UART is recommended. 8250 or 16450 UARTs can be used as well, but they don't have FIFO.
  - Tested with: Texas Instruments TL16C550, Exar ST16C550, National Semiconductor NS16550AFN, California Micro Devices CM16C550, Goldstar GM16C450, and UMC 8250B
* 8255 PPI
  - It is recommended to use higher speed CMOS versions. For example 8 MHz Intersil / Harris CP82C55A part (note CP82C55A-5 is 5 MHz), 10 MHz Toshiba TMP82C55AP-10 or NEC D71055C-10 parts.
  - Tested with: Harris/Intersil CP82C55, TMP82C55AP-10, NEC D71055C-10, Intel 8255-5
* MAX202
  - Can be replaced by pin compatible devices like Maxim MAX232A, Texas Instruments TRS202, or Analog Devices ADM202, that use 0.1uF capacitors for charge pumps.
  - It is possible to use MAX232 or other parts that need 1uF capacitors. In this case capacitors C21 - C24 have to be replaced with 1uF capacitors. Pay attention to capacitors' polarity if using electrolytic capacitors.
* Bi-Level LED Indicator
  - Can be replaced by two 3 mm LEDs with pins bent at 90 degrees.
* Oscillators
  - It is possible to use half can oscillators instead of full can oscillators. In this case install oscillator at pins 4 - 11 . Refer to the PCB silkscreen for oscillator placement.

## Power Supply

Zeta SBC V2 requires a **regulated** 5V power supply. Make sure that the tip of the power supply is the positive lead. System's power consumption varies depending on components used on SBC (CMOS CPU/PPI/UART vs. NMOS components, CMOS logic vs. TTL/LS vs. TTL/ALS) and CPU clock frequency. Also floppy disk drives are relatively power hungry (about 1 A max). Jameco carries quite a few regulated switching 5V wall adapters with different amperage. See these catalog pages:

[http://www.jameco.com/Jameco/catalogs/c113/P105.pdf](http://www.jameco.com/Jameco/catalogs/c113/P105.pdf)

[http://www.jameco.com/Jameco/catalogs/c113/P106.pdf](http://www.jameco.com/Jameco/catalogs/c113/P106.pdf)

Alternatively it is possible to use a linear power supply with 7805 or similar voltage regulator (make sure to use a heatsink, especially if powering a floppy drive).

# Mods

Mods described here were intentionally not implemented on PCB to keep it simple.

* It is possible to use FTDI DB9-USB-M module (Mouser [895-DB9-USB-RS232-M](http://www.mouser.com/ProductDetail/FTDI/DB9-USB-M/?qs=sGAEpiMZZMtcidiSkZ6c9v%252b4CMhdZ6iS)) instead of the serial port connector P3. This module contains RS232 to USB converter IC and provides a mini USB connector. (Alexey, thank you for this tip). It even might be possible to use FTDI DB9-USB-D5-M module, eliminating MAX232A and related capacitors, and connecting the module directly to the UART.
* If you don't plan to use 8255 PPI, it can be omitted. In this case it is not needed to install U5, C5, P4, and JP2.
* It is possible to build Zeta SBC V2 without floppy disk controller (for example for the test purposes, or if you don't need floppy). In this case following components can be omitted: U6, U19, C6, C19, RR1, P5, P6.
* It is possible to build system without RTC, in this case following components can be omitted: U21, X1
* If you don't want battery backup for SRAM, it is possible to omit U22 and BT1. In this case it is needed to connect U22 pin 5 to pin 6 (~RAM_CS) and pin 1 to pin 8 (VCC).

# PCB Versions

## PCB Version 2.0 (Changes from Zeta SBC 1.3)

* Major schematic and PCB change. Board rerouted, most of ICs moved around or shifted.
* Added Z80 CTC
* Replaced FDC9266 floppy disk controller and related discrete logic with WD37C65
* New memory banking implementation.
* Serial port uses RTS/CTS for flow control instead of DSR/DTS.

## Various Ideas

* Image enhancements
  - NVRAM support (BIOS configuration using NVRAM), NVRAM configuration utility
* Enhance utility for programming the BIOS, CP/M, and ROM disk separately. (It already supports the full image programming)
* Add incorrect power supply polarity protection
  - Option 1: Schottky diode in series
  - Option 2: Diode connected in parallel to power supply, in reverse (could be dangerous if power supply is not short circuit protected)
  - Option 3: Use FET

# Files

| Link | Modified |
| :--- | :--- |
| [Zeta SBC V2 - Assembled Board.JPG](files/Zeta%20SBC%20V2%20-%20Assembled%20Board.JPG) (853k) | Sergey Kiselev, Mar 30, 2015, 9:11 AM |
| [Zeta SBC V2 - Board - Color - 2.0.pdf](files/Zeta%20SBC%20V2%20-%20Board%20-%20Color%20-%202.0.pdf) (1200k) | Sergey Kiselev, Jun 15, 2015, 10:48 AM |
| [Zeta SBC V2 - Gerber - 2.0.zip](files/Zeta%20SBC%20V2%20-%20Gerber%20-%202.0.zip) (260k) | Sergey Kiselev, Jun 15, 2015, 10:47 AM |
| [Zeta SBC V2 - KiCad - 2.0.zip](files/Zeta%20SBC%20V2%20-%20KiCad%20-%202.0.zip) (457k) | Sergey Kiselev, Jun 15, 2015, 10:47 AM |
| [Zeta SBC V2 - Schematic - Color - 2.0.pdf](files/Zeta%20SBC%20V2%20-%20Schematic%20-%20Color%20-%202.0.pdf) (210k) | Sergey Kiselev, Jun 15, 2015, 10:48 AM |
| [Zeta with ParPortProp - Perspective View.jpg](files/Zeta%20with%20ParPortProp%20-%20Perspective%20View.jpg) (190k) | Sergey Kiselev, Jan 23, 2015, 11:40 AM |

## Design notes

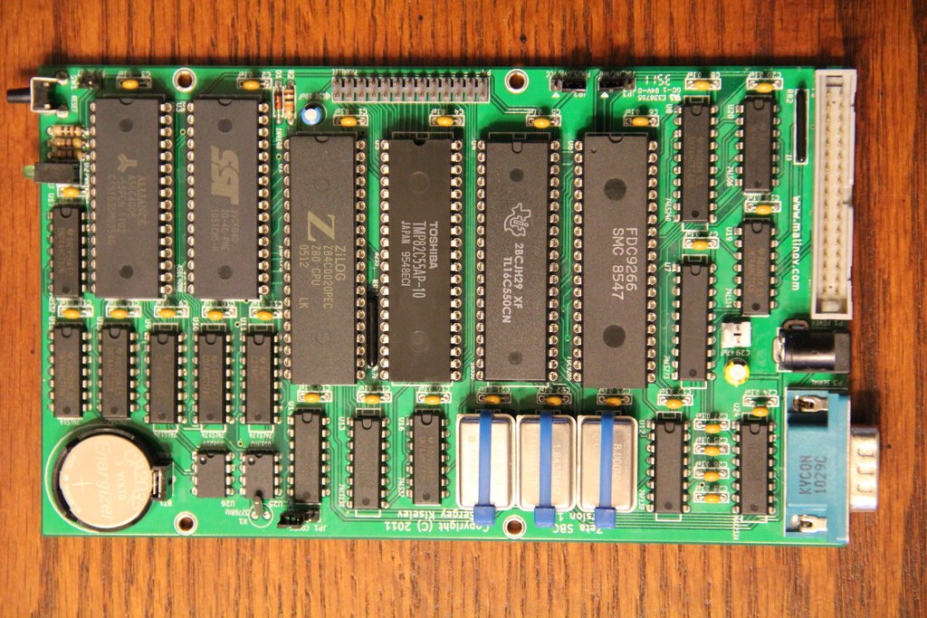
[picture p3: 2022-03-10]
files/Zeta Board.jpg

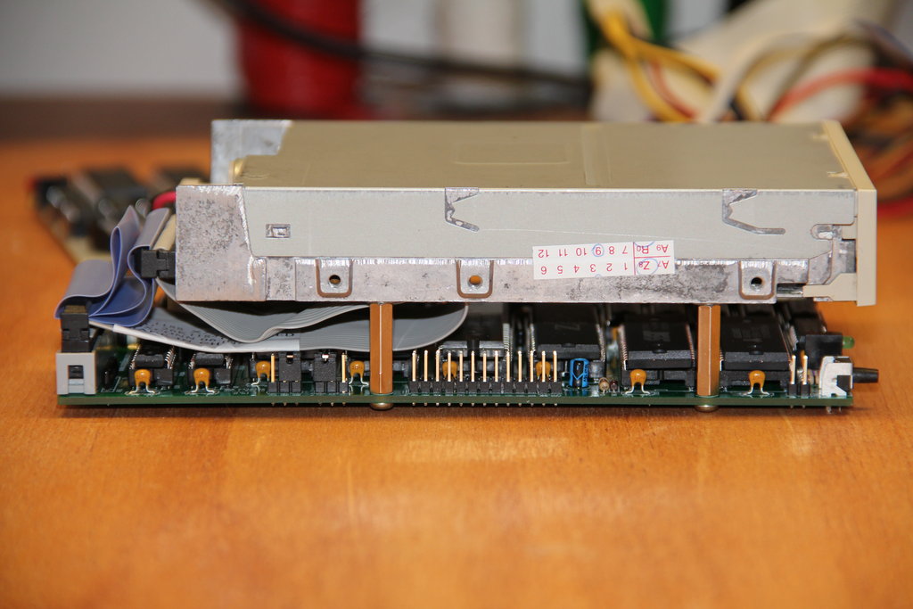
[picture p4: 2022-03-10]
files/Complete System.jpg

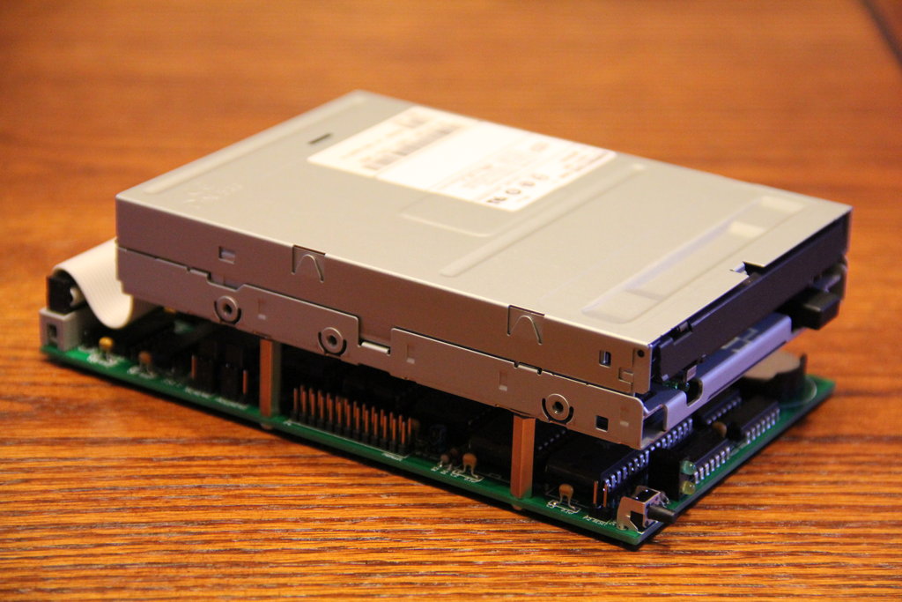
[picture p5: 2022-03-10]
files/Complete System - Perspective View.jpg

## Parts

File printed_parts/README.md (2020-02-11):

# Zeta SBC
3D Printable Enclosure for Zeta SBC and ParPortProp Based System

## Description
This is a 3D printable enclosure for Zeta SBC. This design is inspired by [OpenSCAD Parametric Box by FB Aka Heartman/Hearty](http://heartygfx.blogspot.com).
I did a complete redesign to support the specific requirements I had for the Zeta SBC based system.

This enclosure fits a Zeta SBC or Zeta SBC V2 SBC with a ParPortProp board mounted under it, and a 3.5" floppy drive mounted on top of it.

I've included two front panel designs: The [first one](Zeta-Front-Floppy_with_Bezel.stl) works with regular floppy drives that
have their own bezel. The [second one](Zeta-Front-Floppy_no_Bezel_Sony.stl) works with the Sony MPF920-L drive without bezel.
It is assumed that for the Reset button Zeta SBC uses a tactile switch with the projected plunger and a 4 x 4 mm key top.
Refer to [Recommended Electronic and Hardware Parts](#recommended-electronic-and-hardware-parts) section below for the part numbers.

The boards and the floppy drive are mounted together using eight 15 mm standoffs.
The board stack is then mounted to the bottom of the enclosure using 4 flat head M3 x 12 mm screws that go into the standoffs.
The top part and the bottom parts are secured together using 4 flat head M3 x 8 mm screws going into threaded mounting holes
on the sides of the floppy drive, and 2 flat head M3 x 6 mm screws and 2 sqare nuts placed into the slots in the bottom part.

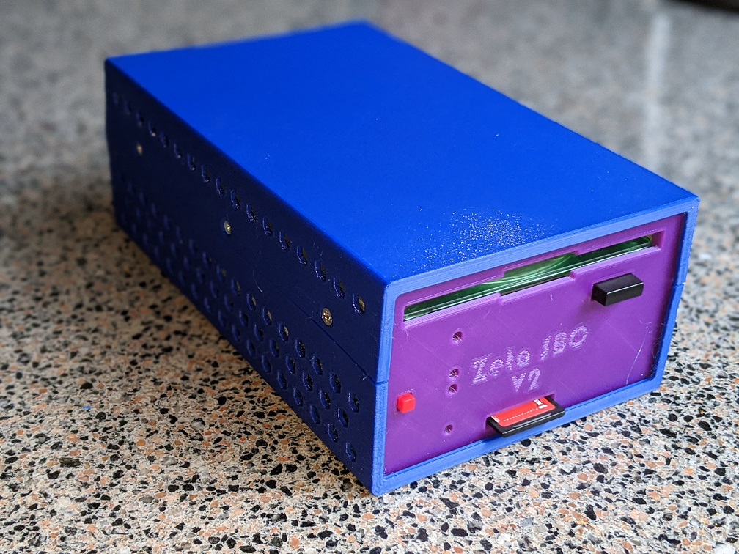
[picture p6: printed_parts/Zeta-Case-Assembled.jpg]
Zeta SBC Case - Assembled


## 3D Printed Parts

* [Enclosure Bottom](Zeta-Bottom.stl)
* [Enclosure Back](Zeta-Back.stl)
* [Enclosure Front with Floppy Drive Cutout](Zeta-Front-Floppy_with_Bezel.stl)
* [Enclosure Front for Sony MPF920-L drive without bezel](Zeta-Front-Floppy_no_Bezel_Sony.stl)
* [Enclosure Top](Zeta-Top.stl)
* [OpenSCAD Source Code](CaseGenerator-Zeta.scad)

### 3D Printing Recommendations

Print these parts with the "flat face" down. Use the "Rotate" function in your slicer software to rotate parts accordingly.
The front and the back parts should be printed with the outer side facing the printer bed.
Make sure to clean any 3D printing artifacts prior to assembling the case.
Use a 3.2 mm (1/8") drill bit to clean the M3 holes in the top and bottom parts.

## Recommended Electronic and Hardware Parts

Part Name      | Description                      | Quantity | Part Number
-------------- | -------------------------------- | -------- | ------------------
Tactile Switch | Right Angle, Projected Plunger   | 1        | Mouser [653-B3F-3152](https://www.mouser.com/ProductDetail/653-B3F-3152)
Key Top        | 4 mm x 4 mm, Red                 | 1        | Mouser [653-B32-1080](https://www.mouser.com/ProductDetail/653-B32-1080)
Standoff       | M3 x 15 mm, Hex, OD: 5 mm, Male/Female | 8  | Mouser [534-24315](https://www.mouser.com/ProductDetail/534-24315)
Screw          | M3 x 12 mm, Hex Drive Flat Socket Cap | 4   | Fastenal [M42510012A40000](https://www.fastenal.com/products/details/M42510012A40000)
Screw          | M3 x 8 mm, Hex Drive Flat Socket Cap | 4    | Fastenal [M42510008A40000](https://www.fastenal.com/products/details/M42510008A40000)
Screw          | M3 x 6 mm, Hex Drive Flat Socket Cap | 2    | Fastenal [M42510006A40000](https://www.fastenal.com/products/details/M42510006A40000)
Nut            | M3 x 1.8 mm, Square Nut          | 2        | Fastenal [0161907](https://www.fastenal.com/products/details/0161907)

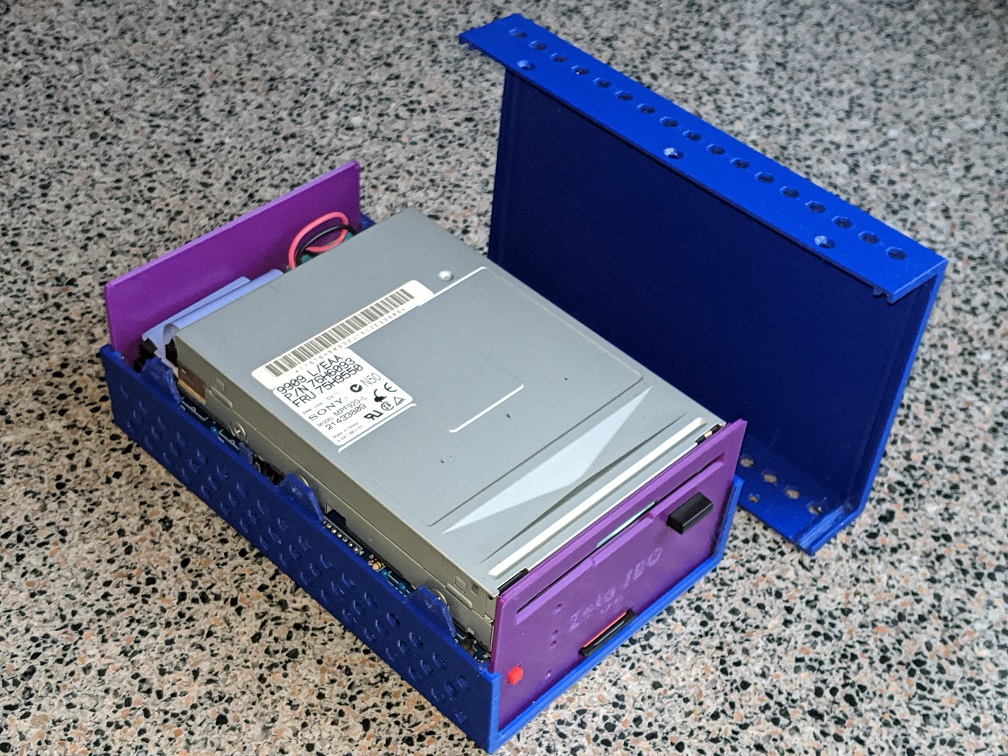
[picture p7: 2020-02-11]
printed_parts/Zeta-Case-Open.jpg

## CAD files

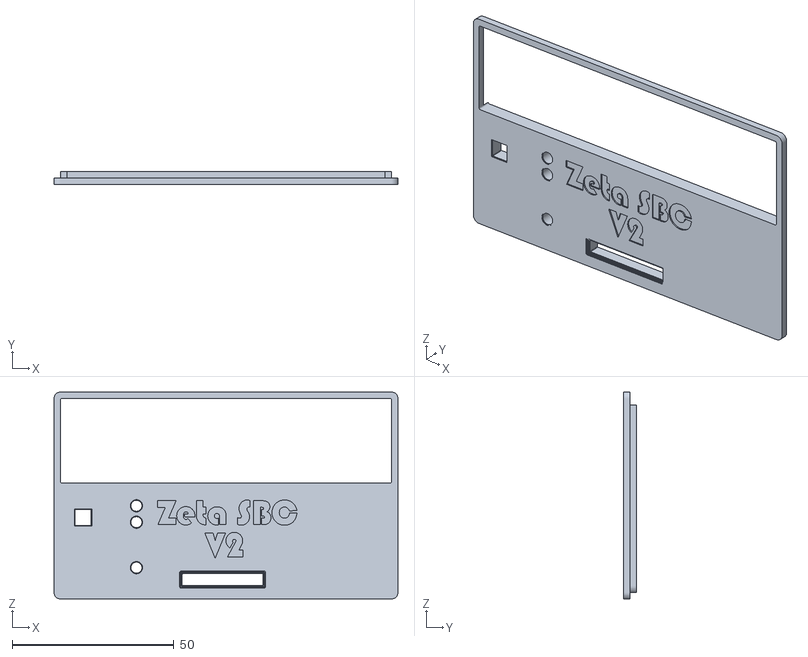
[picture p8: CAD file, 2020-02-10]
printed_parts/Zeta-Front-Floppy_with_Bezel.stl
106.4 x 4.00 x 64.0

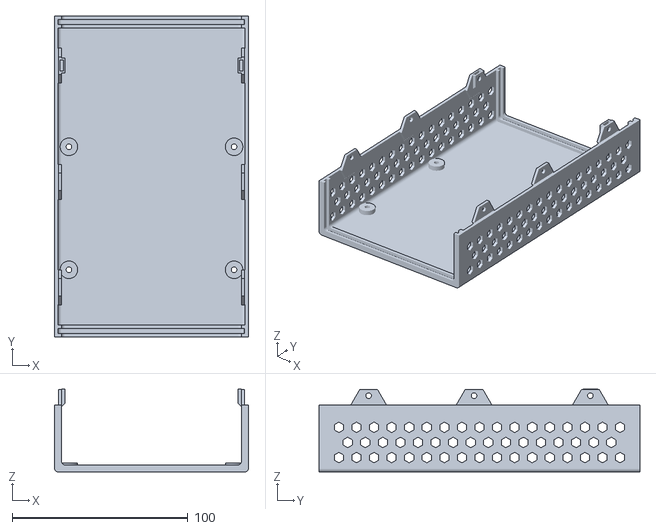
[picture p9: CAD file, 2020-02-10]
printed_parts/Zeta-Bottom.stl
110.4 x 182.6 x 47.2

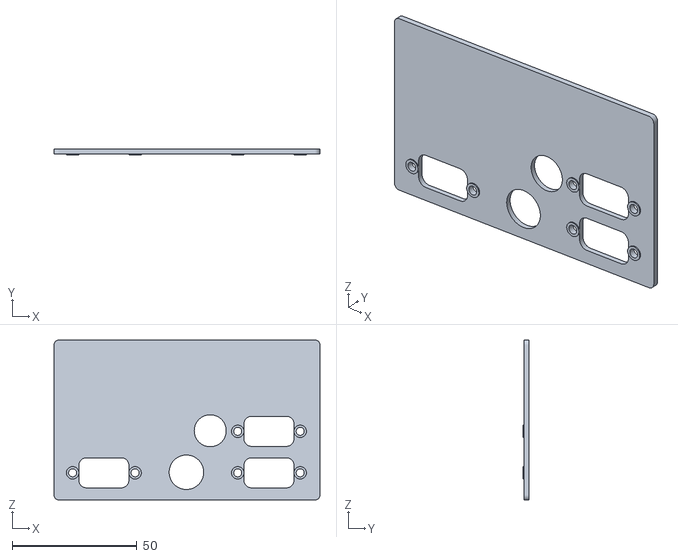
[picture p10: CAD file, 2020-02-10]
printed_parts/Zeta-Back.stl
106.4 x 2.40 x 64.0

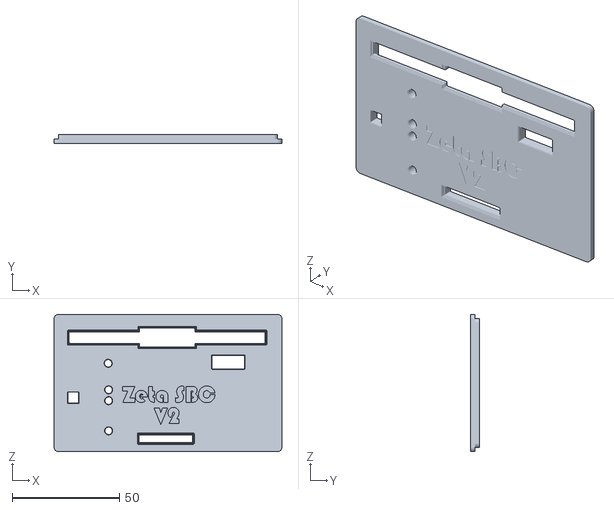
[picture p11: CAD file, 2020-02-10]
printed_parts/Zeta-Front-Floppy_no_Bezel_Sony.stl
106.4 x 4.00 x 64.0

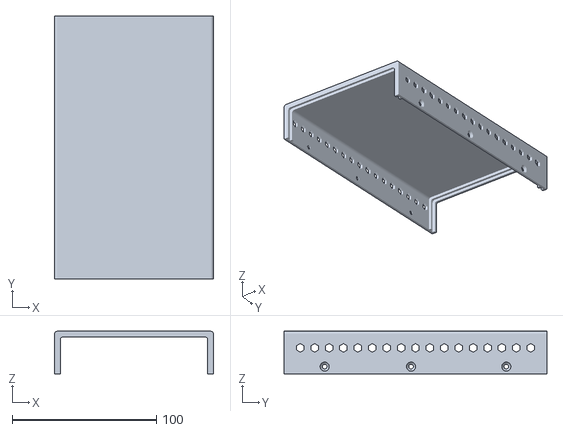
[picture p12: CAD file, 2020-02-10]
printed_parts/Zeta-Top.stl
110.4 x 182.6 x 29.6

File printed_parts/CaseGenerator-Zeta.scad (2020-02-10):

////////////////////////////////////////////////////////////////////////////////
// Parametric Case Generator for Electronic Projects
// Copyright (C) 2020 Sergey Kiselev
// 
// Inspired by FB Aka Heartman/Hearty 2016 OpenScad Parametric Box
// http://heartygfx.blogspot.com
////////////////////////////////////////////////////////////////////////////////

////////////////////////////////////////////////////////////////////////////////
// Notes:
// The case dimensions are the internal dimensions. The external dimensions
//   are automatically calculated based on the internal dimensions, the wall
//   thickness, and the PCB supports height. The internal height does not include
//   the height of the PCB standoffs
// The origin for the top and the bottom of the case
//   is left/front/bottom of the PCB
// The origin for the front panel is left/0/bottom of the PCB
// The origin for the back panel is right/0/bottom of the PCB. It is mirrored
//   relative to the front panel, so that it can be printed with the face down

// Rendering control. Set respective value to 1 to render the part, or to 0 to
//   skip rendering
top = 1;
bottom = 1;
front = 1;
back = 1;
vent = 1; // Render ventilation holes
standoffs = 0; // Render PCB standoffs
// Project specific - Zeta SBC. Set to 1 to render the front panel with
// a large rectangular cutout for the floppy drive. Set to 0 to render the front
// panel to be used with the Sony MPF920L floppy drive without bezel.
floppy_bezel = 0;

// Project-specific settings
pcb_thick = 1.6;
board_spacing = 15; // distance between two boards (standoffs length)

// Inside dimensions of the case
length = 172.18; // the actual board length 170.18 + front_thick-thick
width = 101.6;
height = (pcb_thick+board_spacing)*2+25.4;
// Middle - indicates the height at which the top/bottom connecting screws
//   are placed
middle = (pcb_thick+board_spacing)*2+5;

// Parameters
// Tolerance - added to the internal dimensions and also to the slots width for
//   the front and the back panels
xy = 0.4; // tolerance for X/Y
z = 0.2; // tolerance for Z
// Resolution for the cylinder shapes (holes, case corners).
//   Indicates the number of rectangular segments per cylinder
r = 60;
// Wall thickness
thick = 2;
// Front panel thickness
front_thick = 4;
// Back panel thickness
back_thick = 2;
// Radius of the corners for the top and the bottom
corner_radius = 2;
// Diameter of the ventilation holes
vent_diameter = 6;
// Spacing of the ventilation holes
vent_y_spacing = 10;
vent_z_spacing = 8.6;
// Standoffs height from the inner side of the bottom of the case to the 
//   bottom of the PCB. To ensure proper front panel fit, it is recommended
//   that the standoffs height would be more than or equal to wall thickenss
standoff_height = 3;
// Standoffs outer diameter
standoff_diameter = 10;
// Ear parameters
// Location (Y/depth) of the mounting ears (relative to the board front)
// and hex nut slot - 0 = no hex nut slot, 1 = hex nut slot
// Zeta - removed two middle ears, and add slot for a hex nut for the back ear?
//ear_params = [[21,0], [21+60,0], [21+90,0], [length-21,1]];
ear_params = [[23,0], [23+60,0], [length-23,1]];
// Standoff parameters 
// Location X,Y relative to front left corner of the PCB
standoff_params = [[(width-94)/2,(front_thick-thick)+31],[(width-94)/2,(front_thick-thick)+31+70],[width-(width-94)/2,(front_thick-thick)+31],[width-(width-94)/2,(front_thick-thick)+31+70]];
// Holes diameter
hole_diameter = 3.2;
// Screw head diameter
head_diameter = 6+xy;
// Mounting ears radius
ears_radius = 10;
// The height of the mounting holes in the ears, relative to the middle line
hole_height = 5;
// Nut slot inside dimensions
nut_width = 5.5;
nut_thick = 1.6;
// Nut slot outside dimensions - Width of the nut slot across corners
nut_slot_width = 8.6;
nut_slot_height = 7.6;
// Top / bottom color
color1 = "Orange";
// Panels color
color2 = "OrangeRed";

// Dimensions calculations
// External width - walls thickness added two times, once for the
//   actual wall, another one for the hinge/connector
ext_width = width+thick*4+xy*2;
// External length - tolernace is added 6 times, twice for each panel slot
//   and once for the tolerance between the wall and the PCB
ext_length = length+thick*4+xy*6;
// External height - thickenss is added 3 times, twice for the wall
//   thickness and once for the panel slot
ext_height = height+standoff_height+thick*3+z*2;
bottom_height = middle-hole_height+standoff_height+thick+z;
top_height = height-middle+hole_height+thick*2+z;

render_case();

module render_case () {
    if (top == 1 || bottom == 1) color (color1) case();
    if (front == 1) {
        color(color2) {
            translate([thick+xy,thick*2+xy-front_thick,thick+z]) {
                front_panel();
            }
        }
    }

    if (back == 1) {
        color(color2) {
            translate([ext_width-(thick+xy),ext_length-(thick*2+xy)+back_thick,thick+z]) rotate([0,0,180]) {
                back_panel();
            }
        }
    }
}
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

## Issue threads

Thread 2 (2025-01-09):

Suggestion: Clock divider instead of 8 plus 16 MHz oscillators

elosha, 2025-01-09:
Hi, I really the Zeta concept. But I would like to suggest a modification:

Since V1.0, there are three osciallators: 1.8432 MHz (SIO baud rate and CTC timing), 8 MHz (CPU clock) and 16 MHz (FDC timing).

8 is only half of 16, so one would think a 4bit counter as clock divider might as well do the job, while offering multiple clock rate choices at the sime time (easier debugging, tinkering, faster/slower CPU substitution). Plus, TTL logic is cheaper and a bit easier to obtain than crystal oscillators.

What do you think? 😊

skiselev, 2025-01-09:
Three oscillators allow for the most flexibility. It is possible to set arbitrary CPU frequency without impacting the FDC.
For example, on my own Zeta SBC V2 boards, I used 20 MHz CPU frequency.

While using a divider might be a cheaper option (the oscillator costs around $2.5, while an 74HCT logic IC costs around $0.60), it will reduce the flexibility. That is, the CPU frequency will need to be a multiply of the UART base frequency, or a quotient of the FDC frequency...

Now if you want to save an oscillator in your own build, you can get a 20 MHz CPU, and run it on 16 MHz frequency. Just add a wire between pin 8 of U17 and pin 8 of U19.

elosha, 2025-01-10:
Thanks for explaining the decision behind this, it makes sense :) Also thanks for the hint with 16MHz CPU clock.

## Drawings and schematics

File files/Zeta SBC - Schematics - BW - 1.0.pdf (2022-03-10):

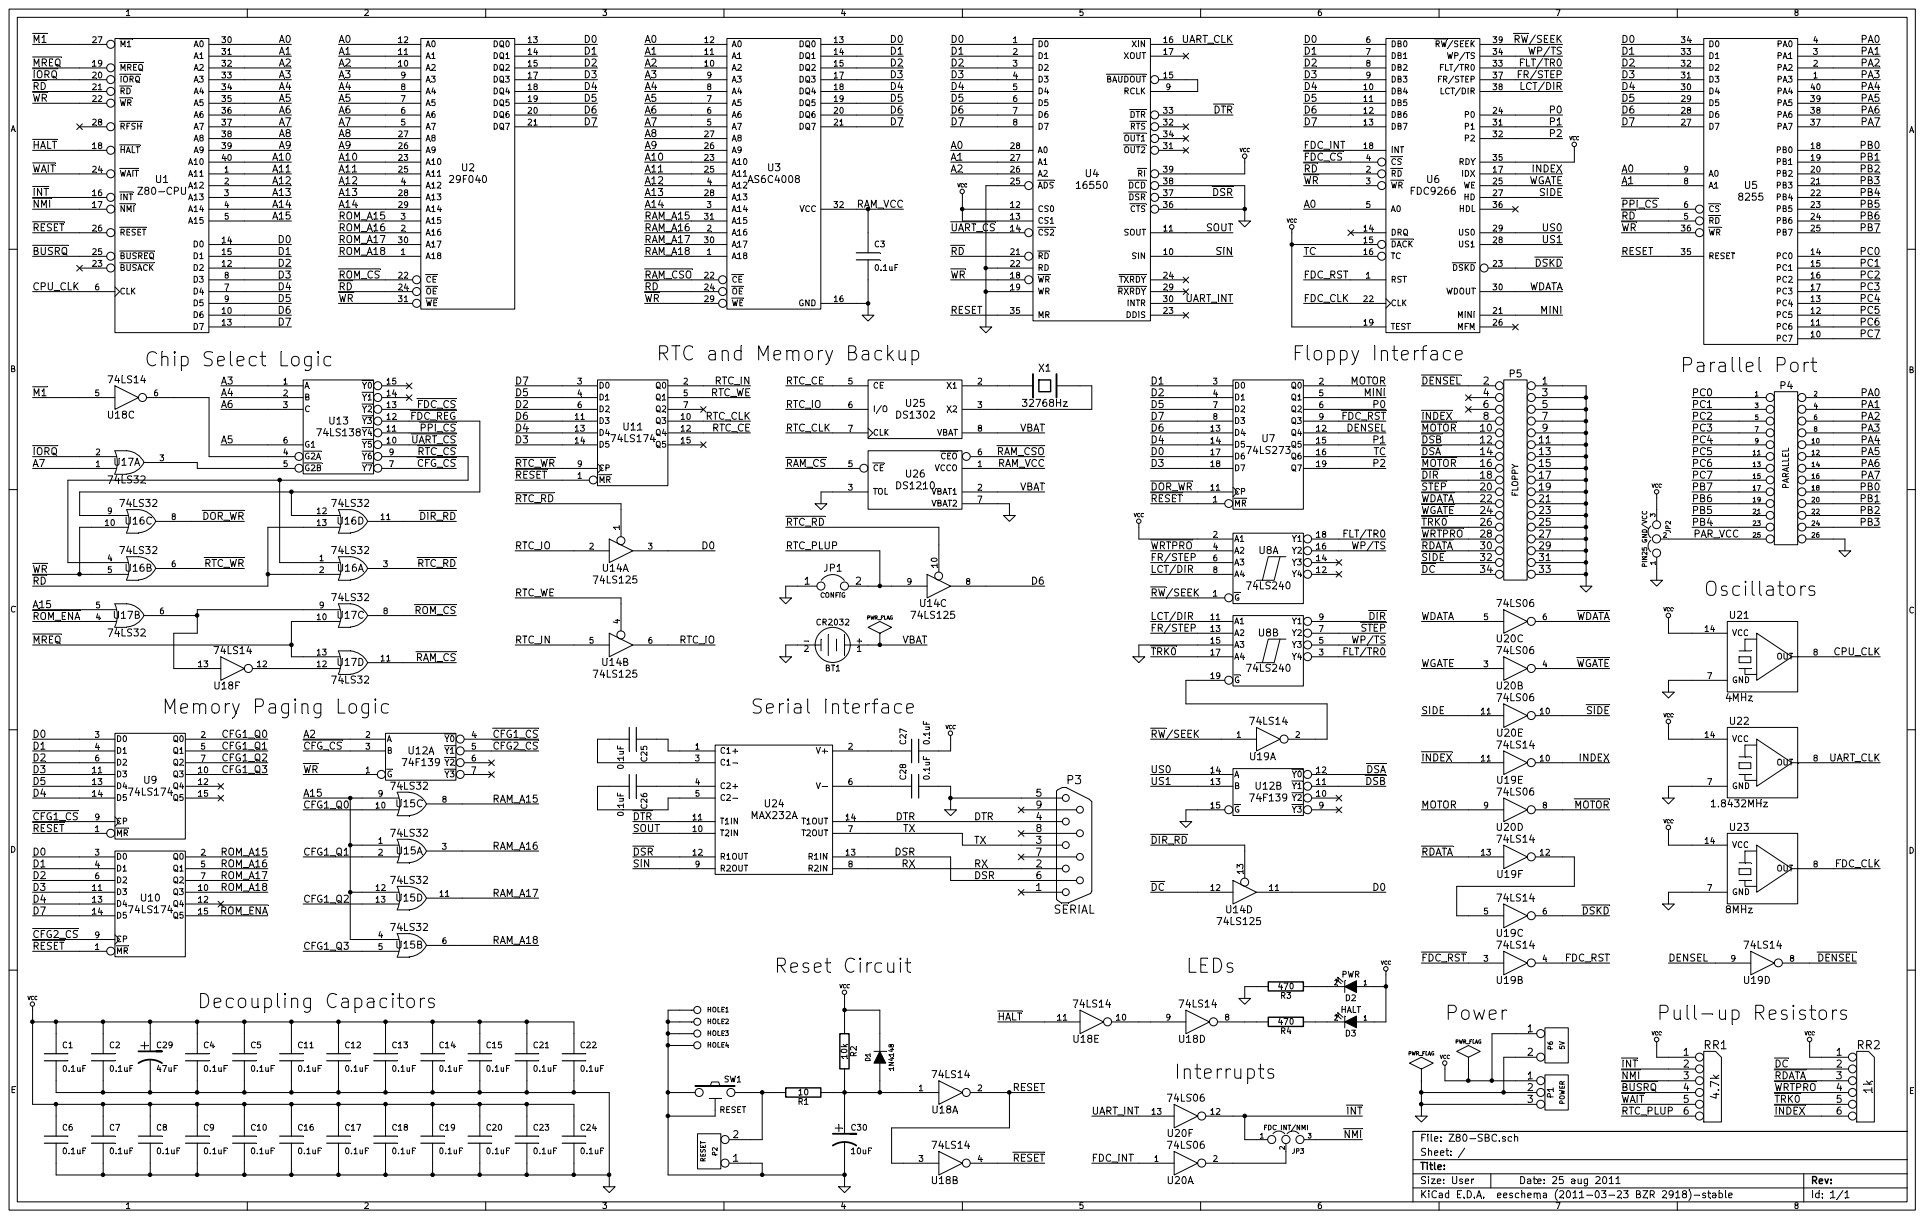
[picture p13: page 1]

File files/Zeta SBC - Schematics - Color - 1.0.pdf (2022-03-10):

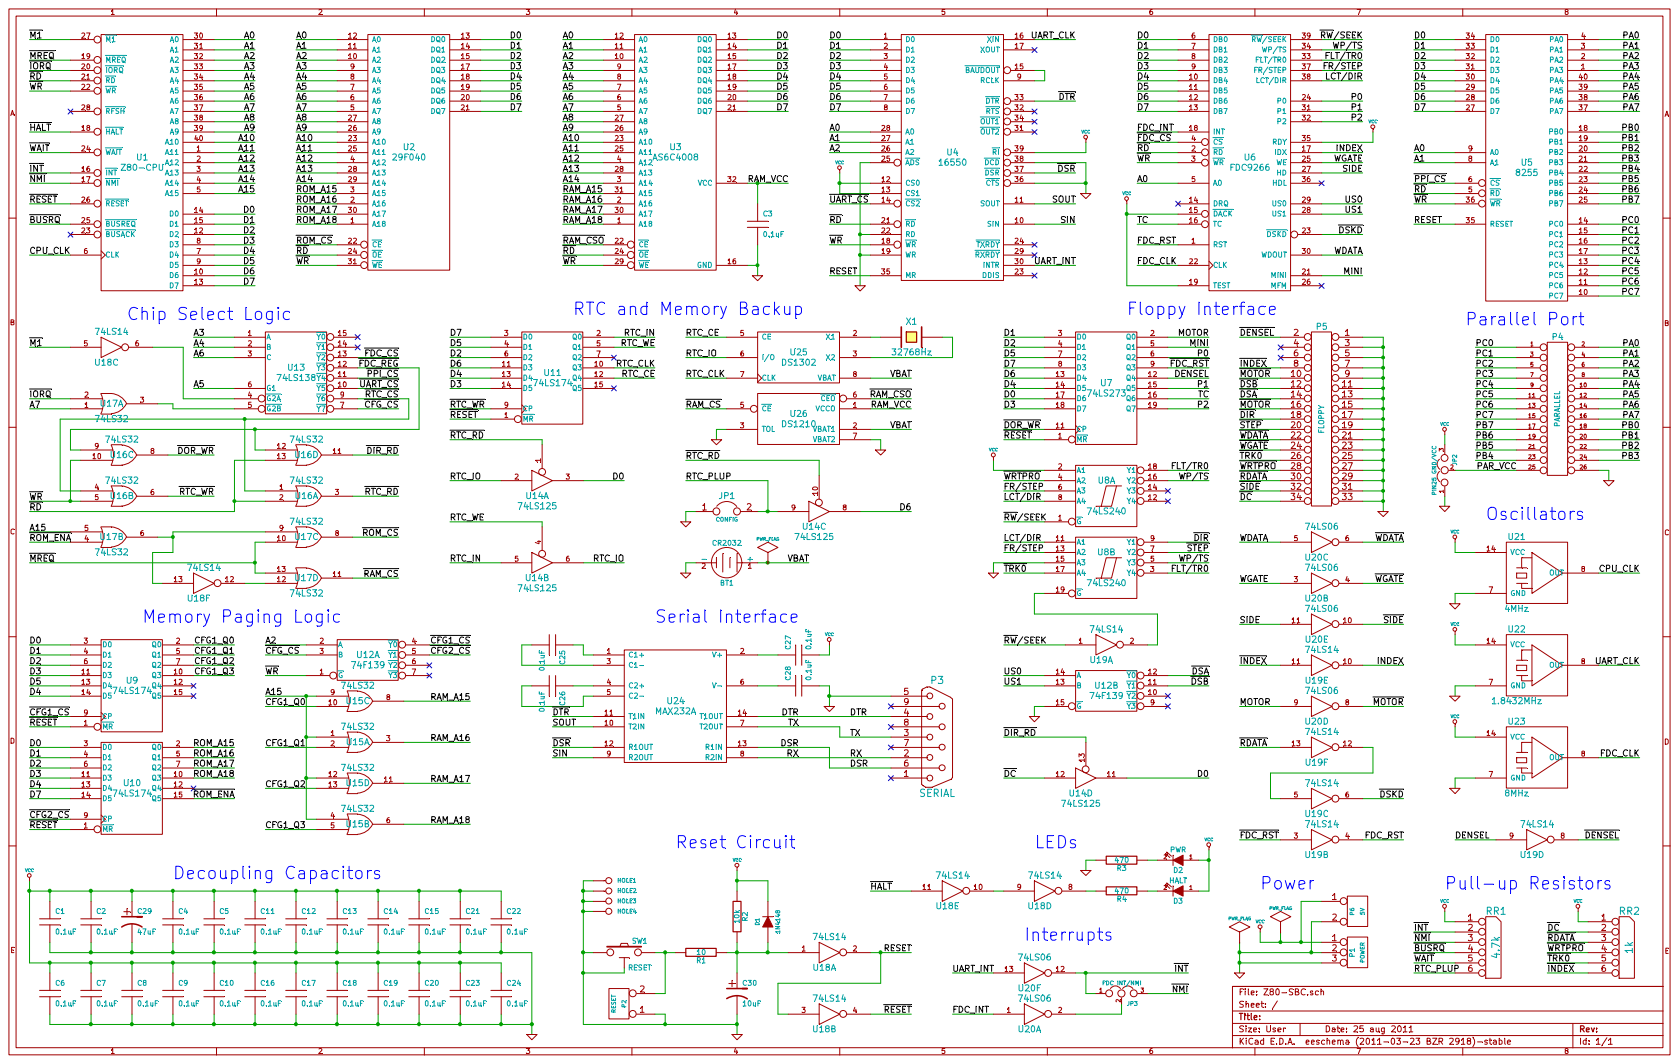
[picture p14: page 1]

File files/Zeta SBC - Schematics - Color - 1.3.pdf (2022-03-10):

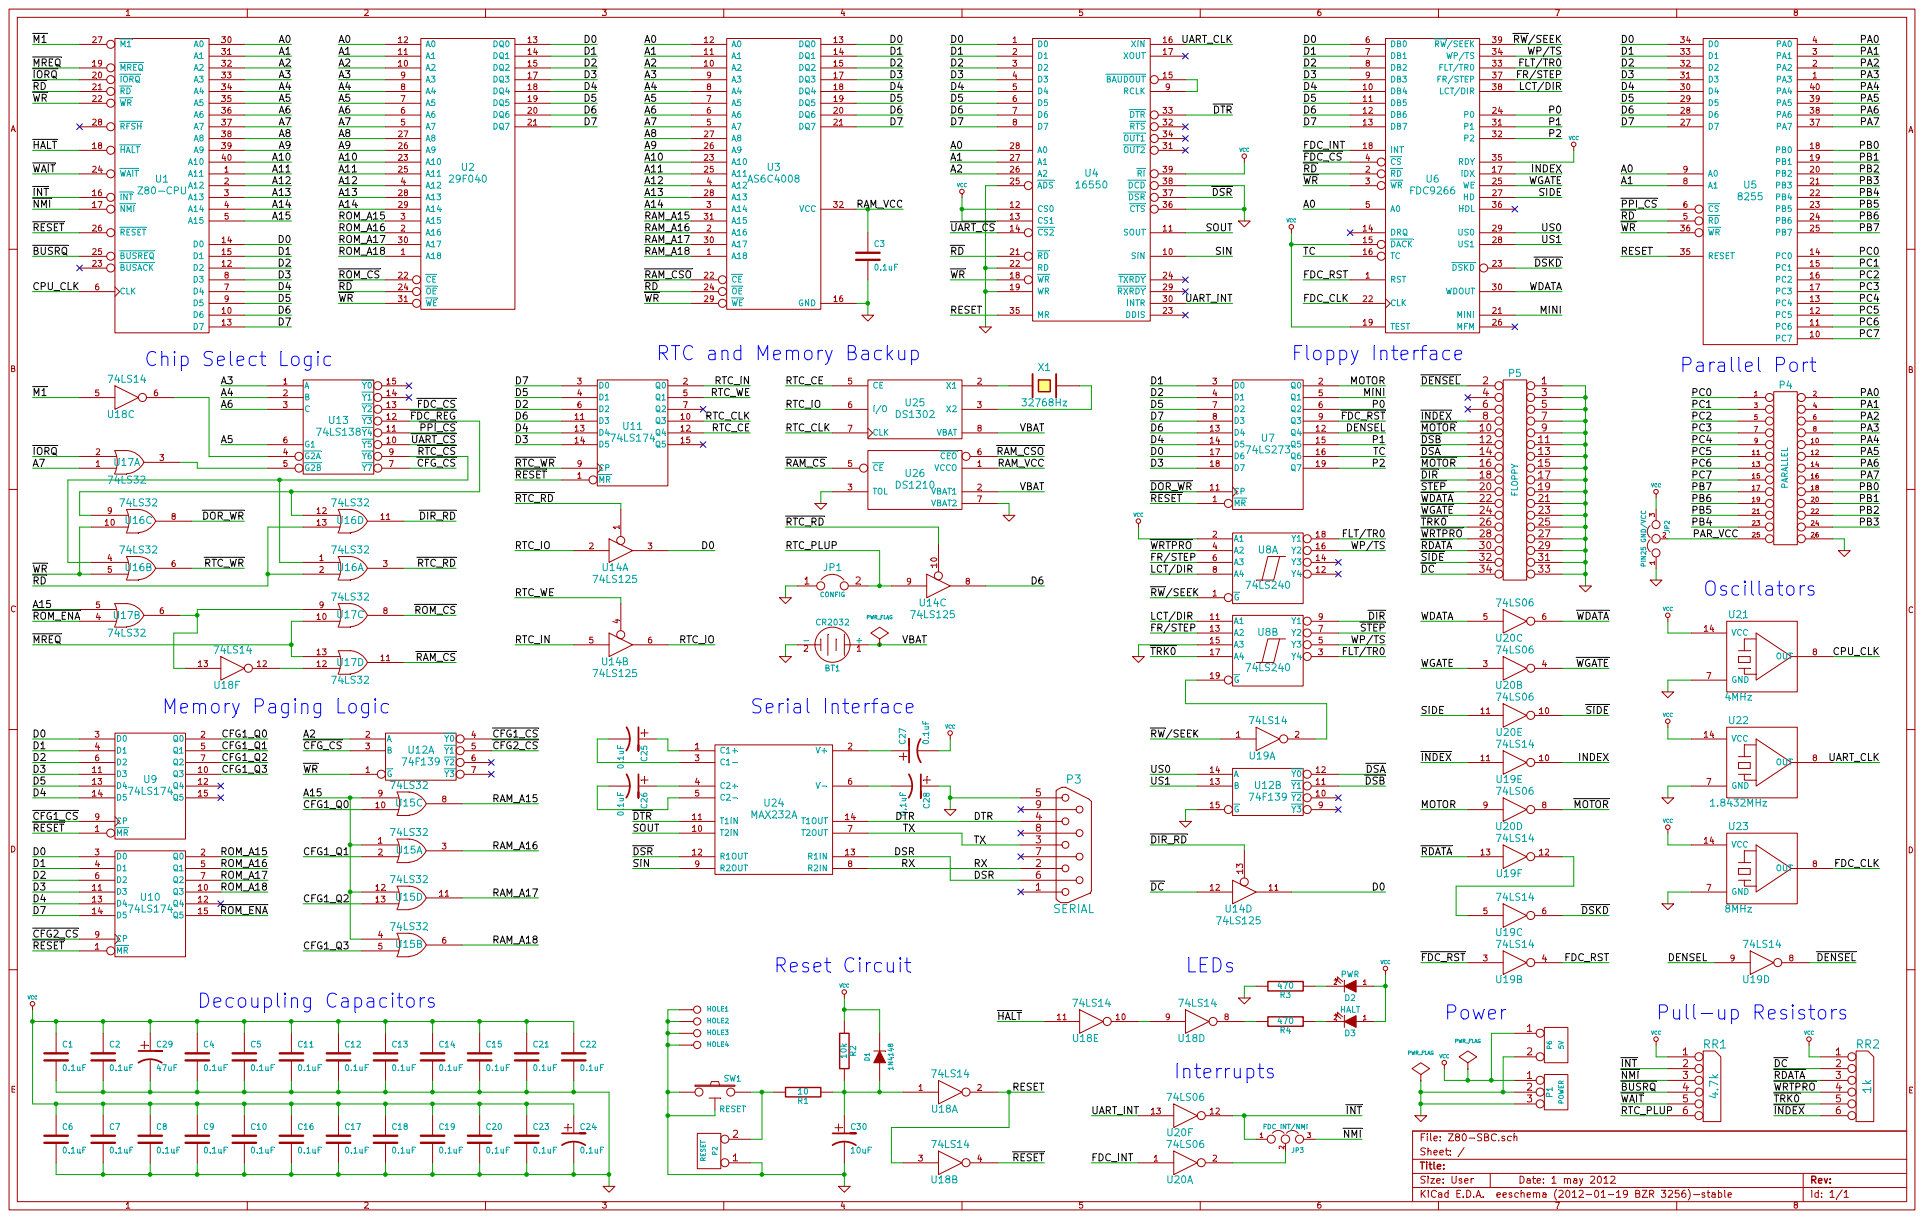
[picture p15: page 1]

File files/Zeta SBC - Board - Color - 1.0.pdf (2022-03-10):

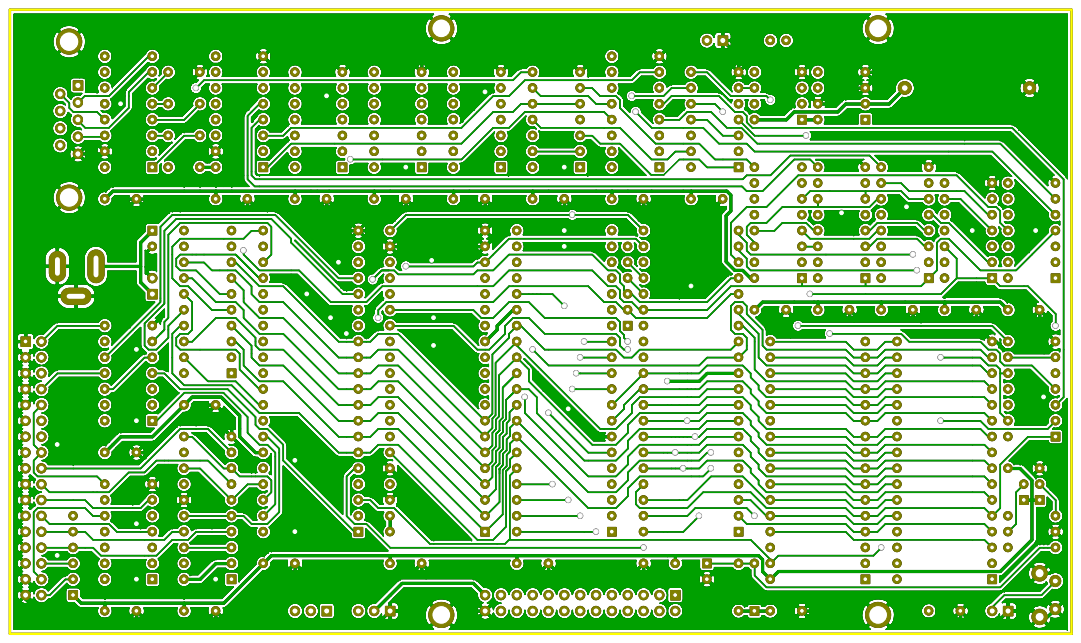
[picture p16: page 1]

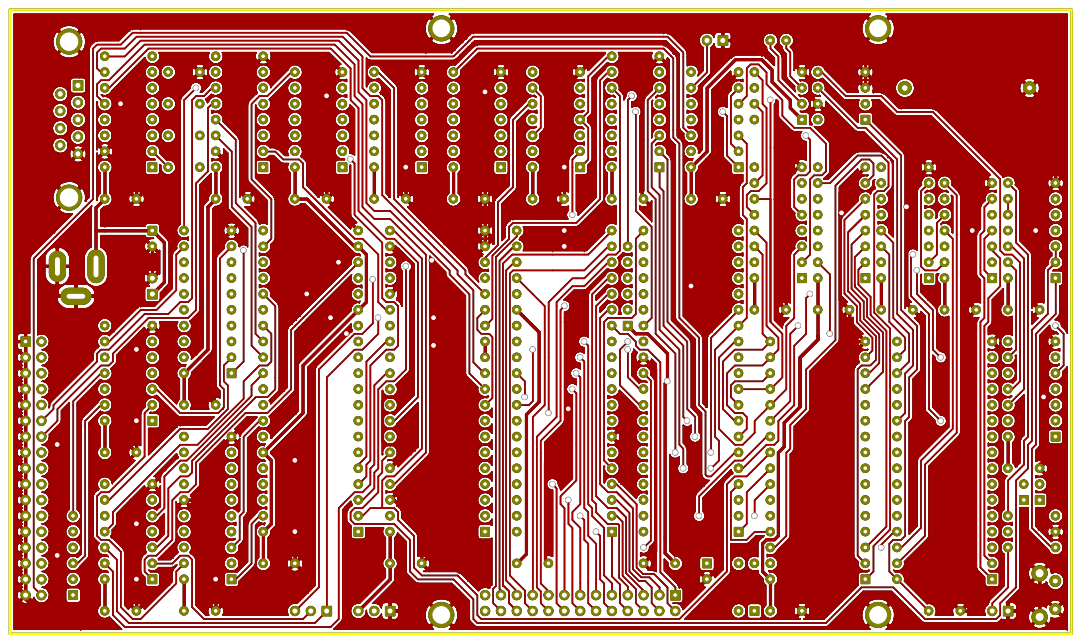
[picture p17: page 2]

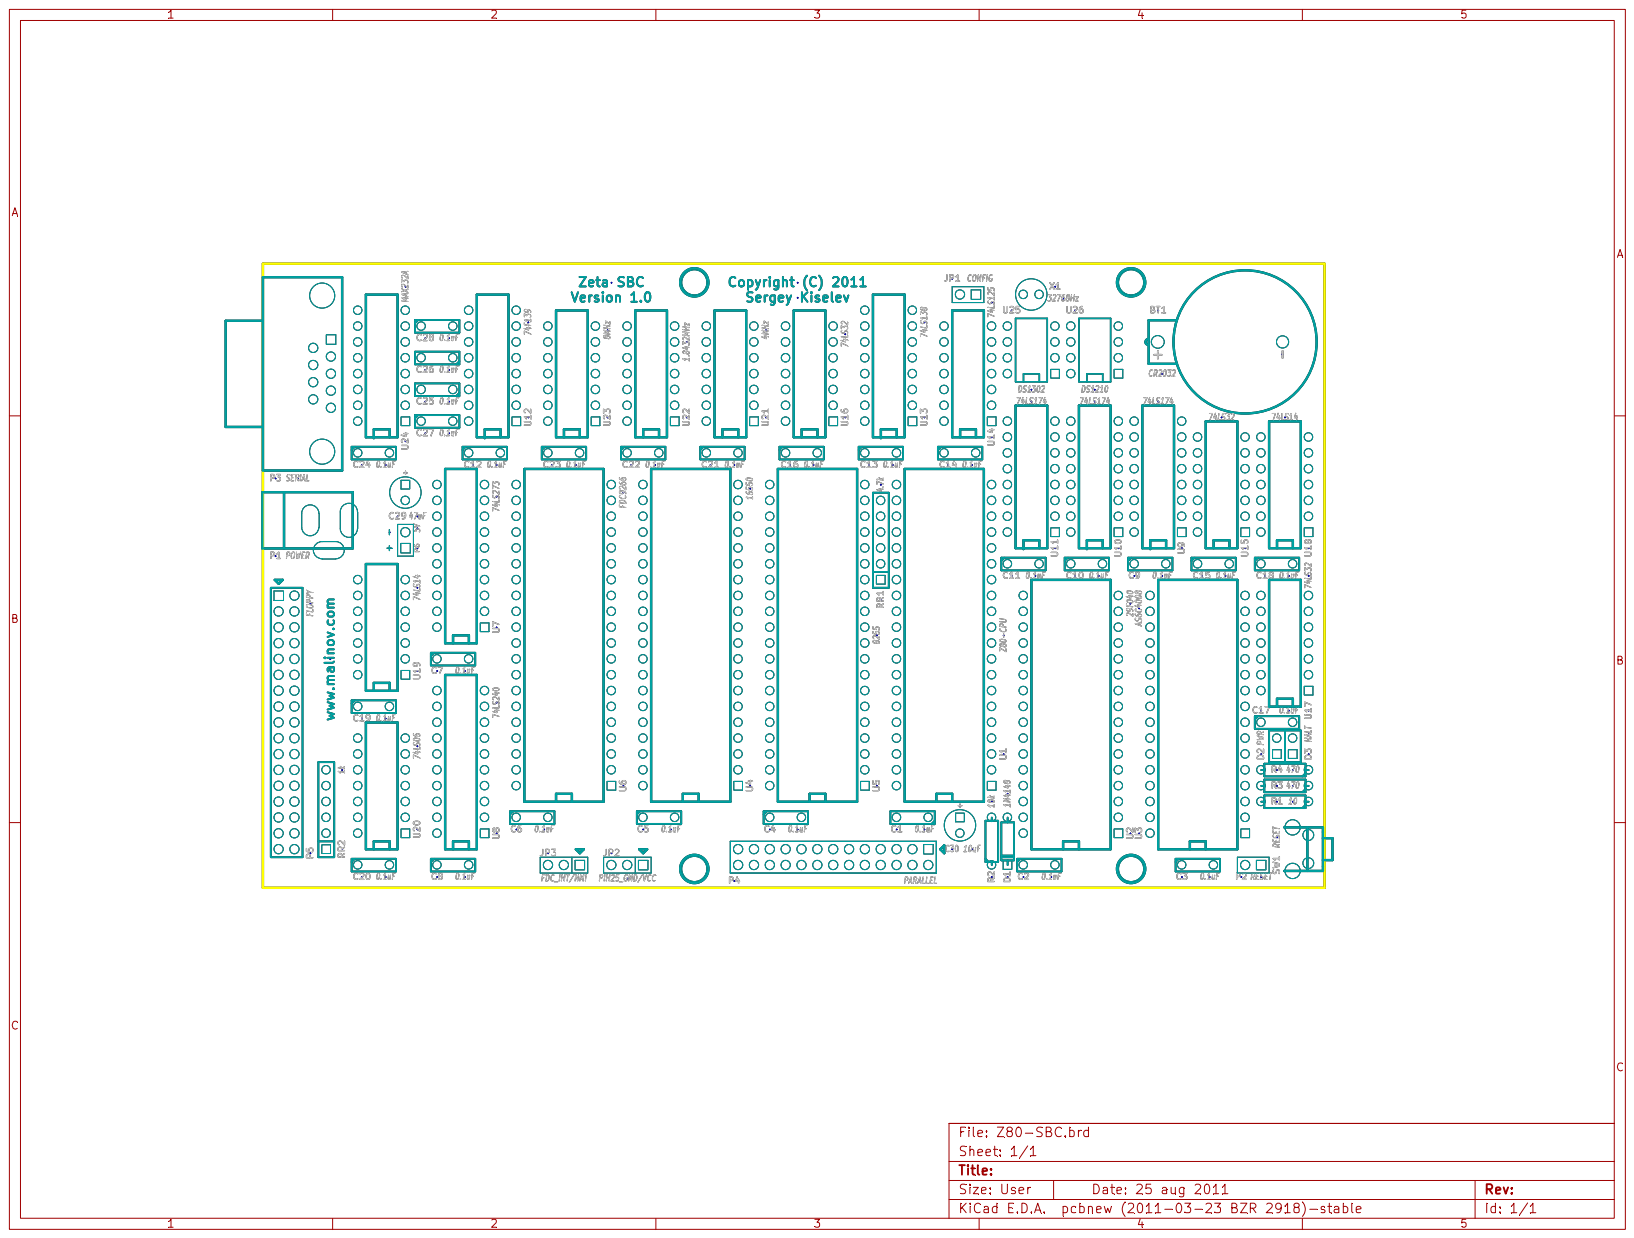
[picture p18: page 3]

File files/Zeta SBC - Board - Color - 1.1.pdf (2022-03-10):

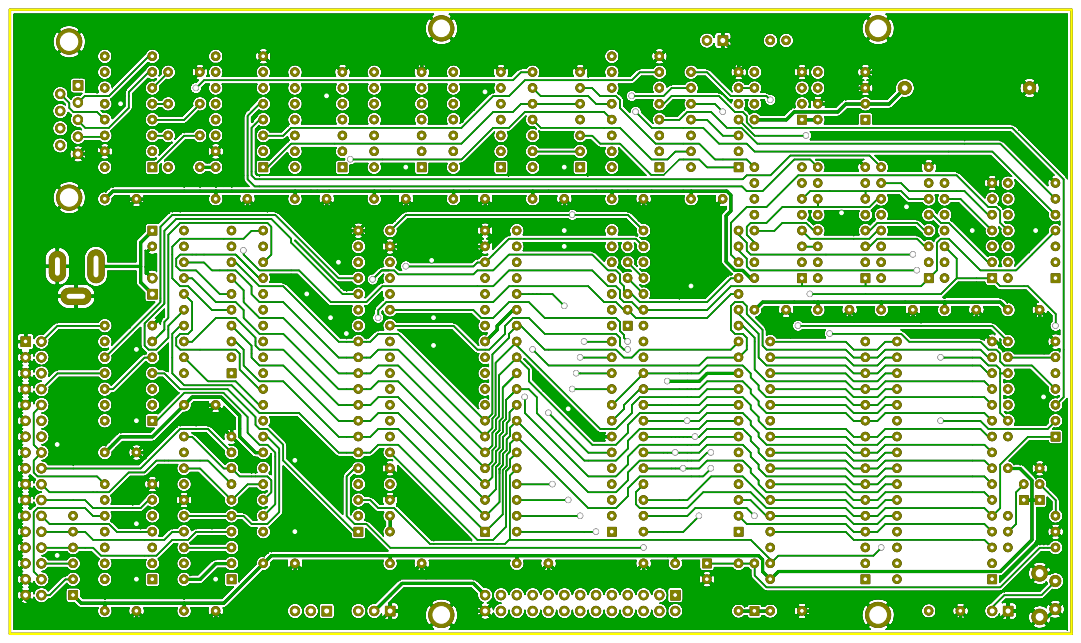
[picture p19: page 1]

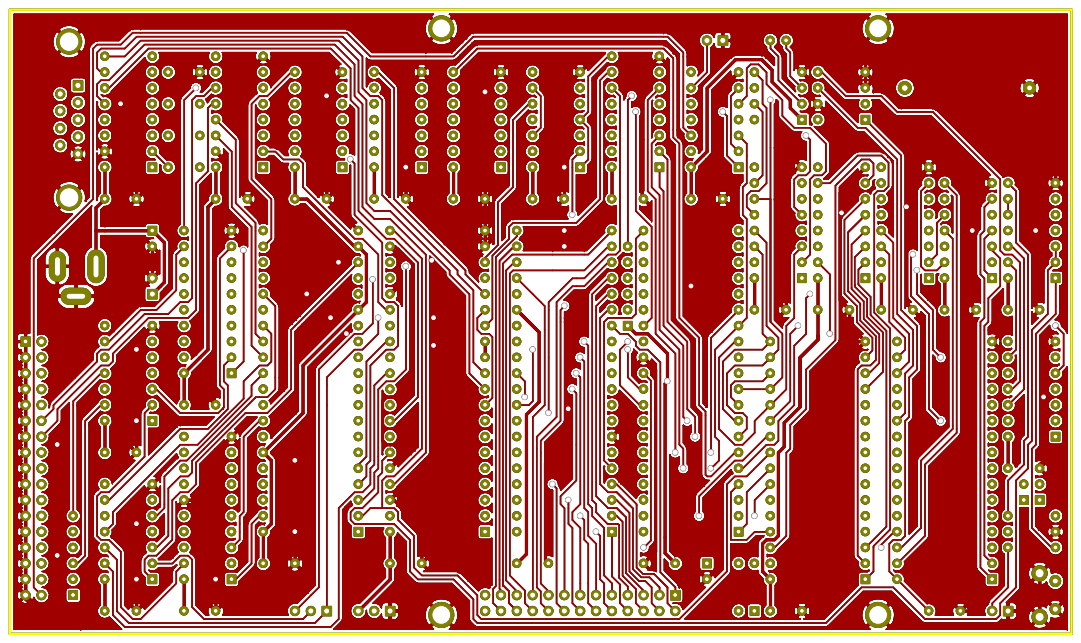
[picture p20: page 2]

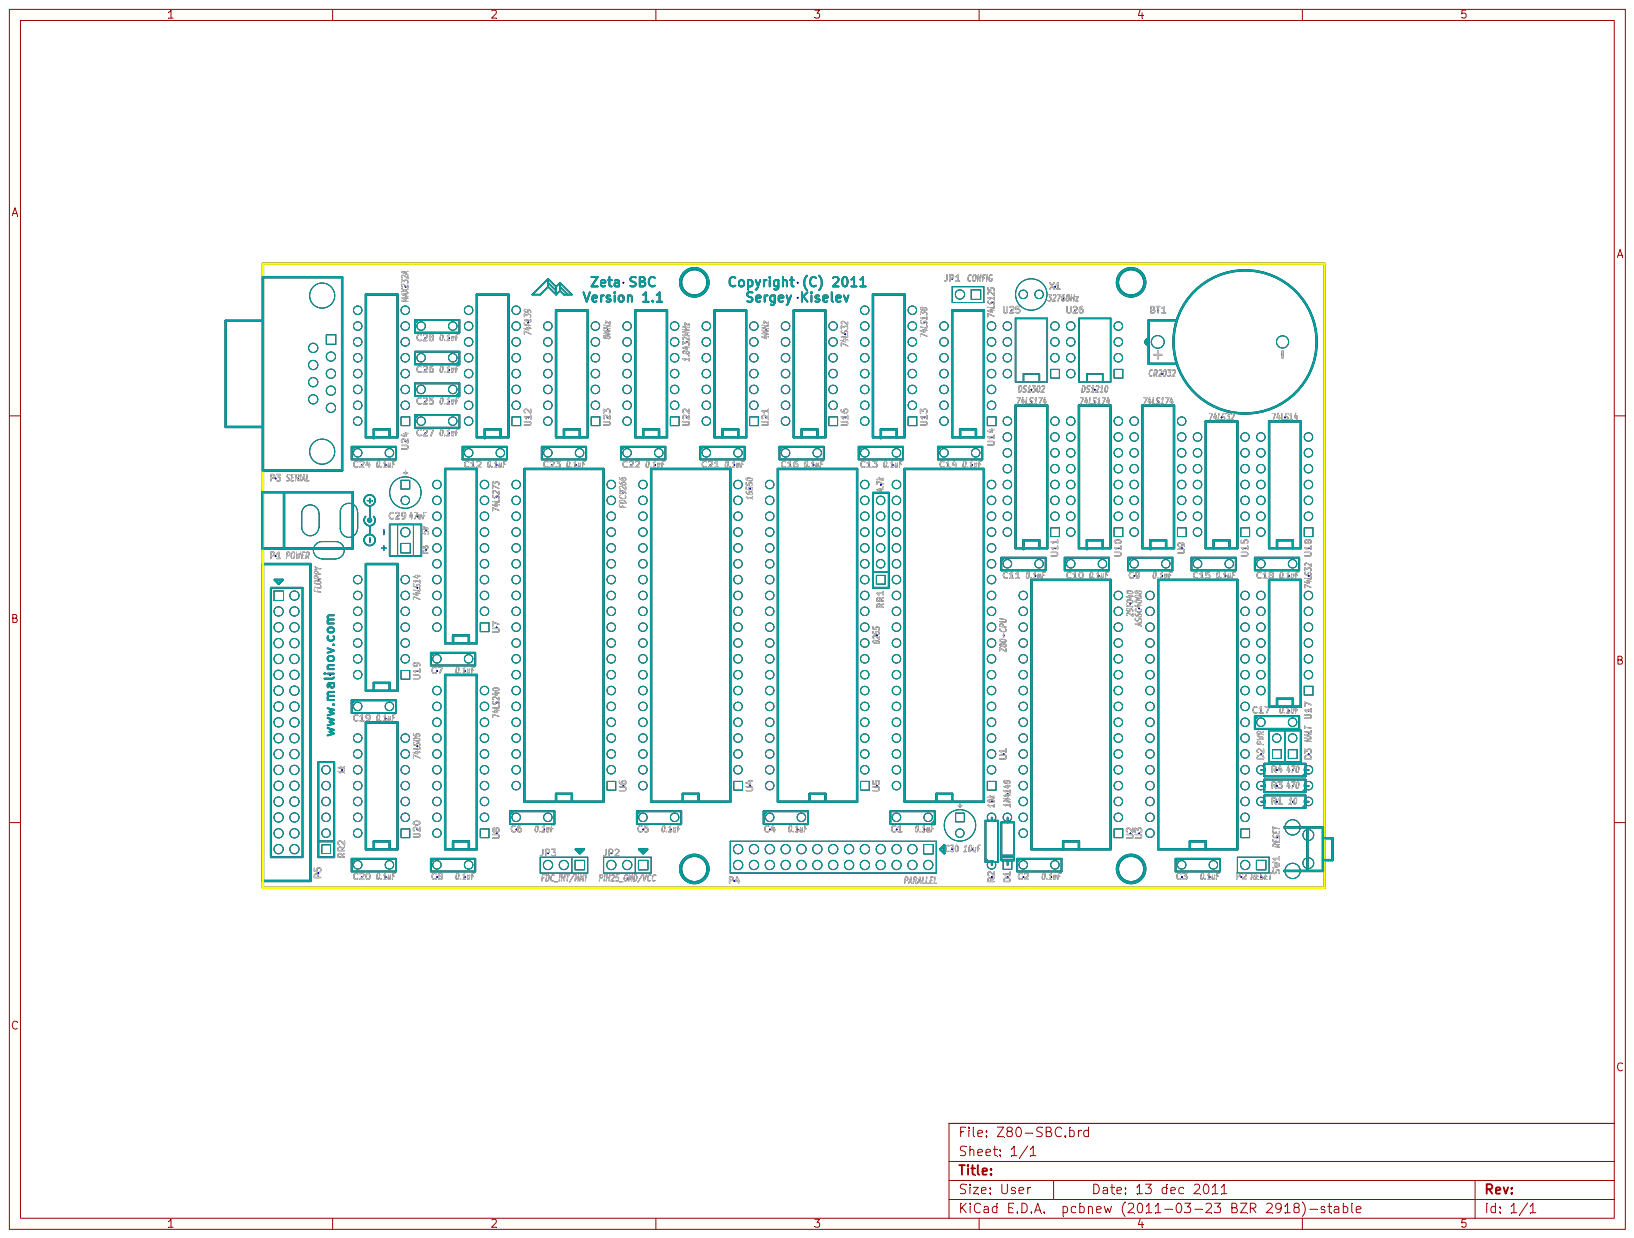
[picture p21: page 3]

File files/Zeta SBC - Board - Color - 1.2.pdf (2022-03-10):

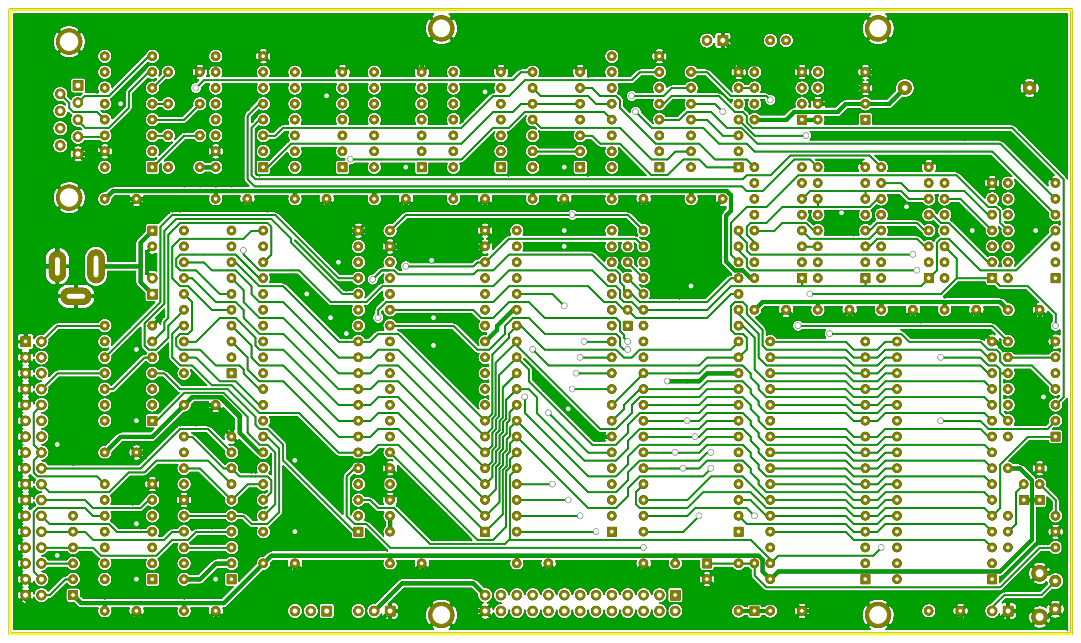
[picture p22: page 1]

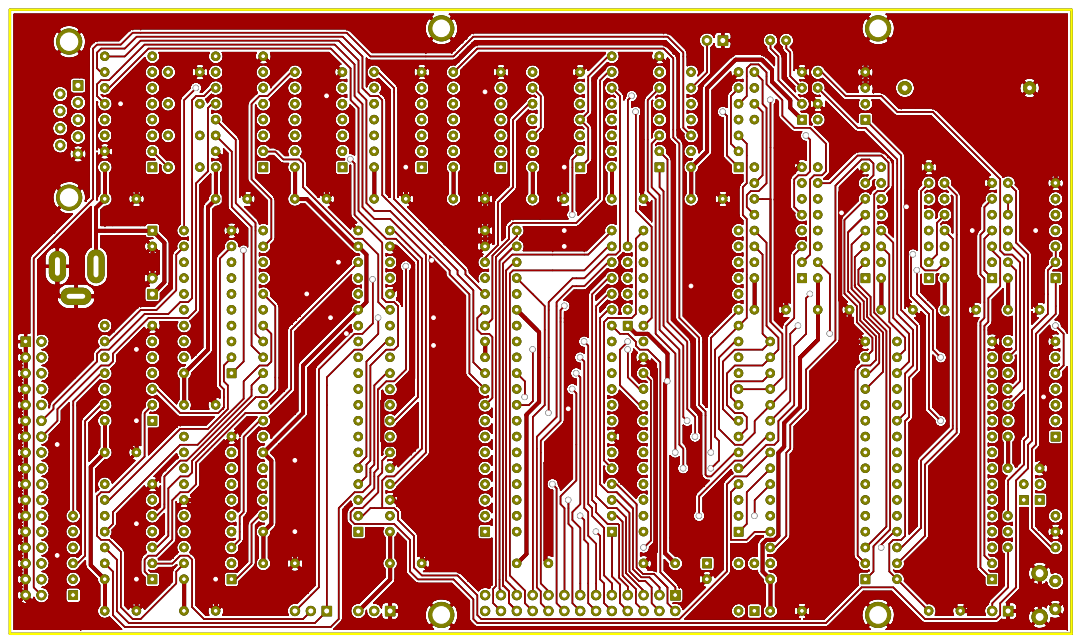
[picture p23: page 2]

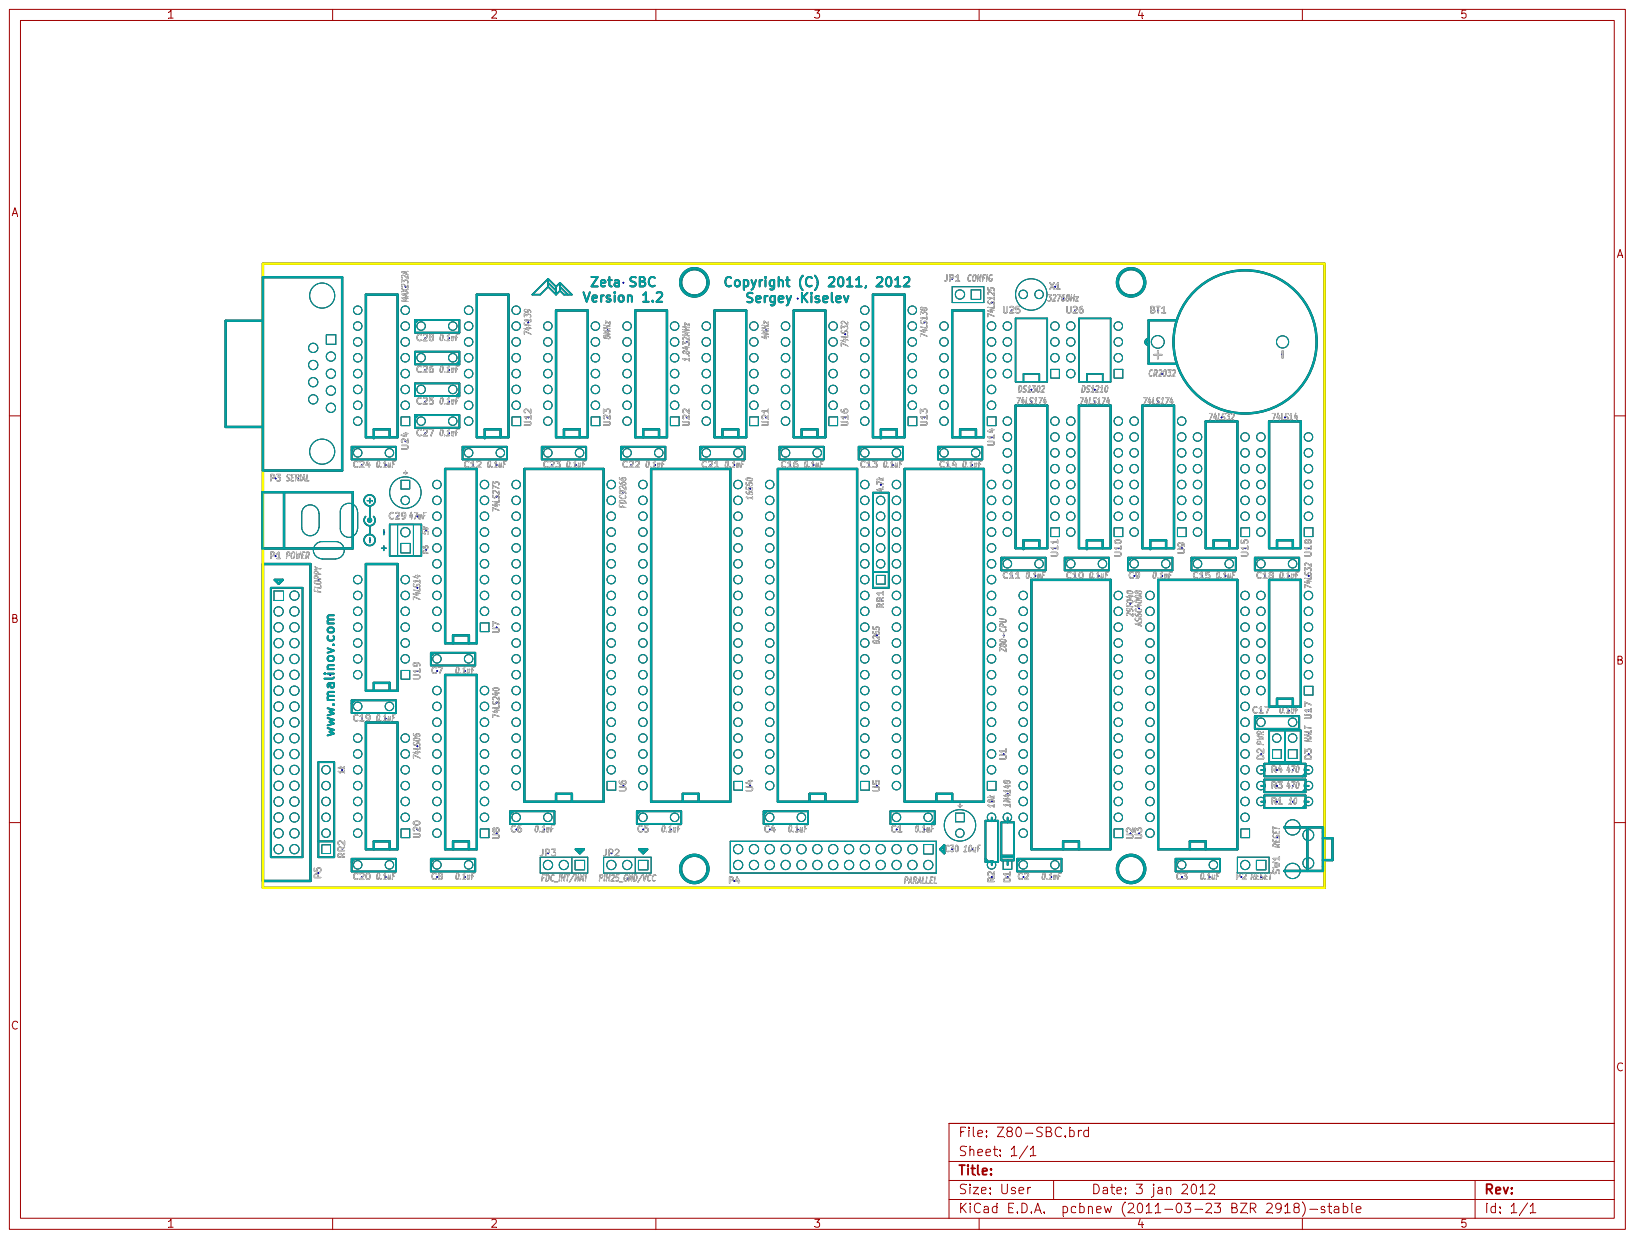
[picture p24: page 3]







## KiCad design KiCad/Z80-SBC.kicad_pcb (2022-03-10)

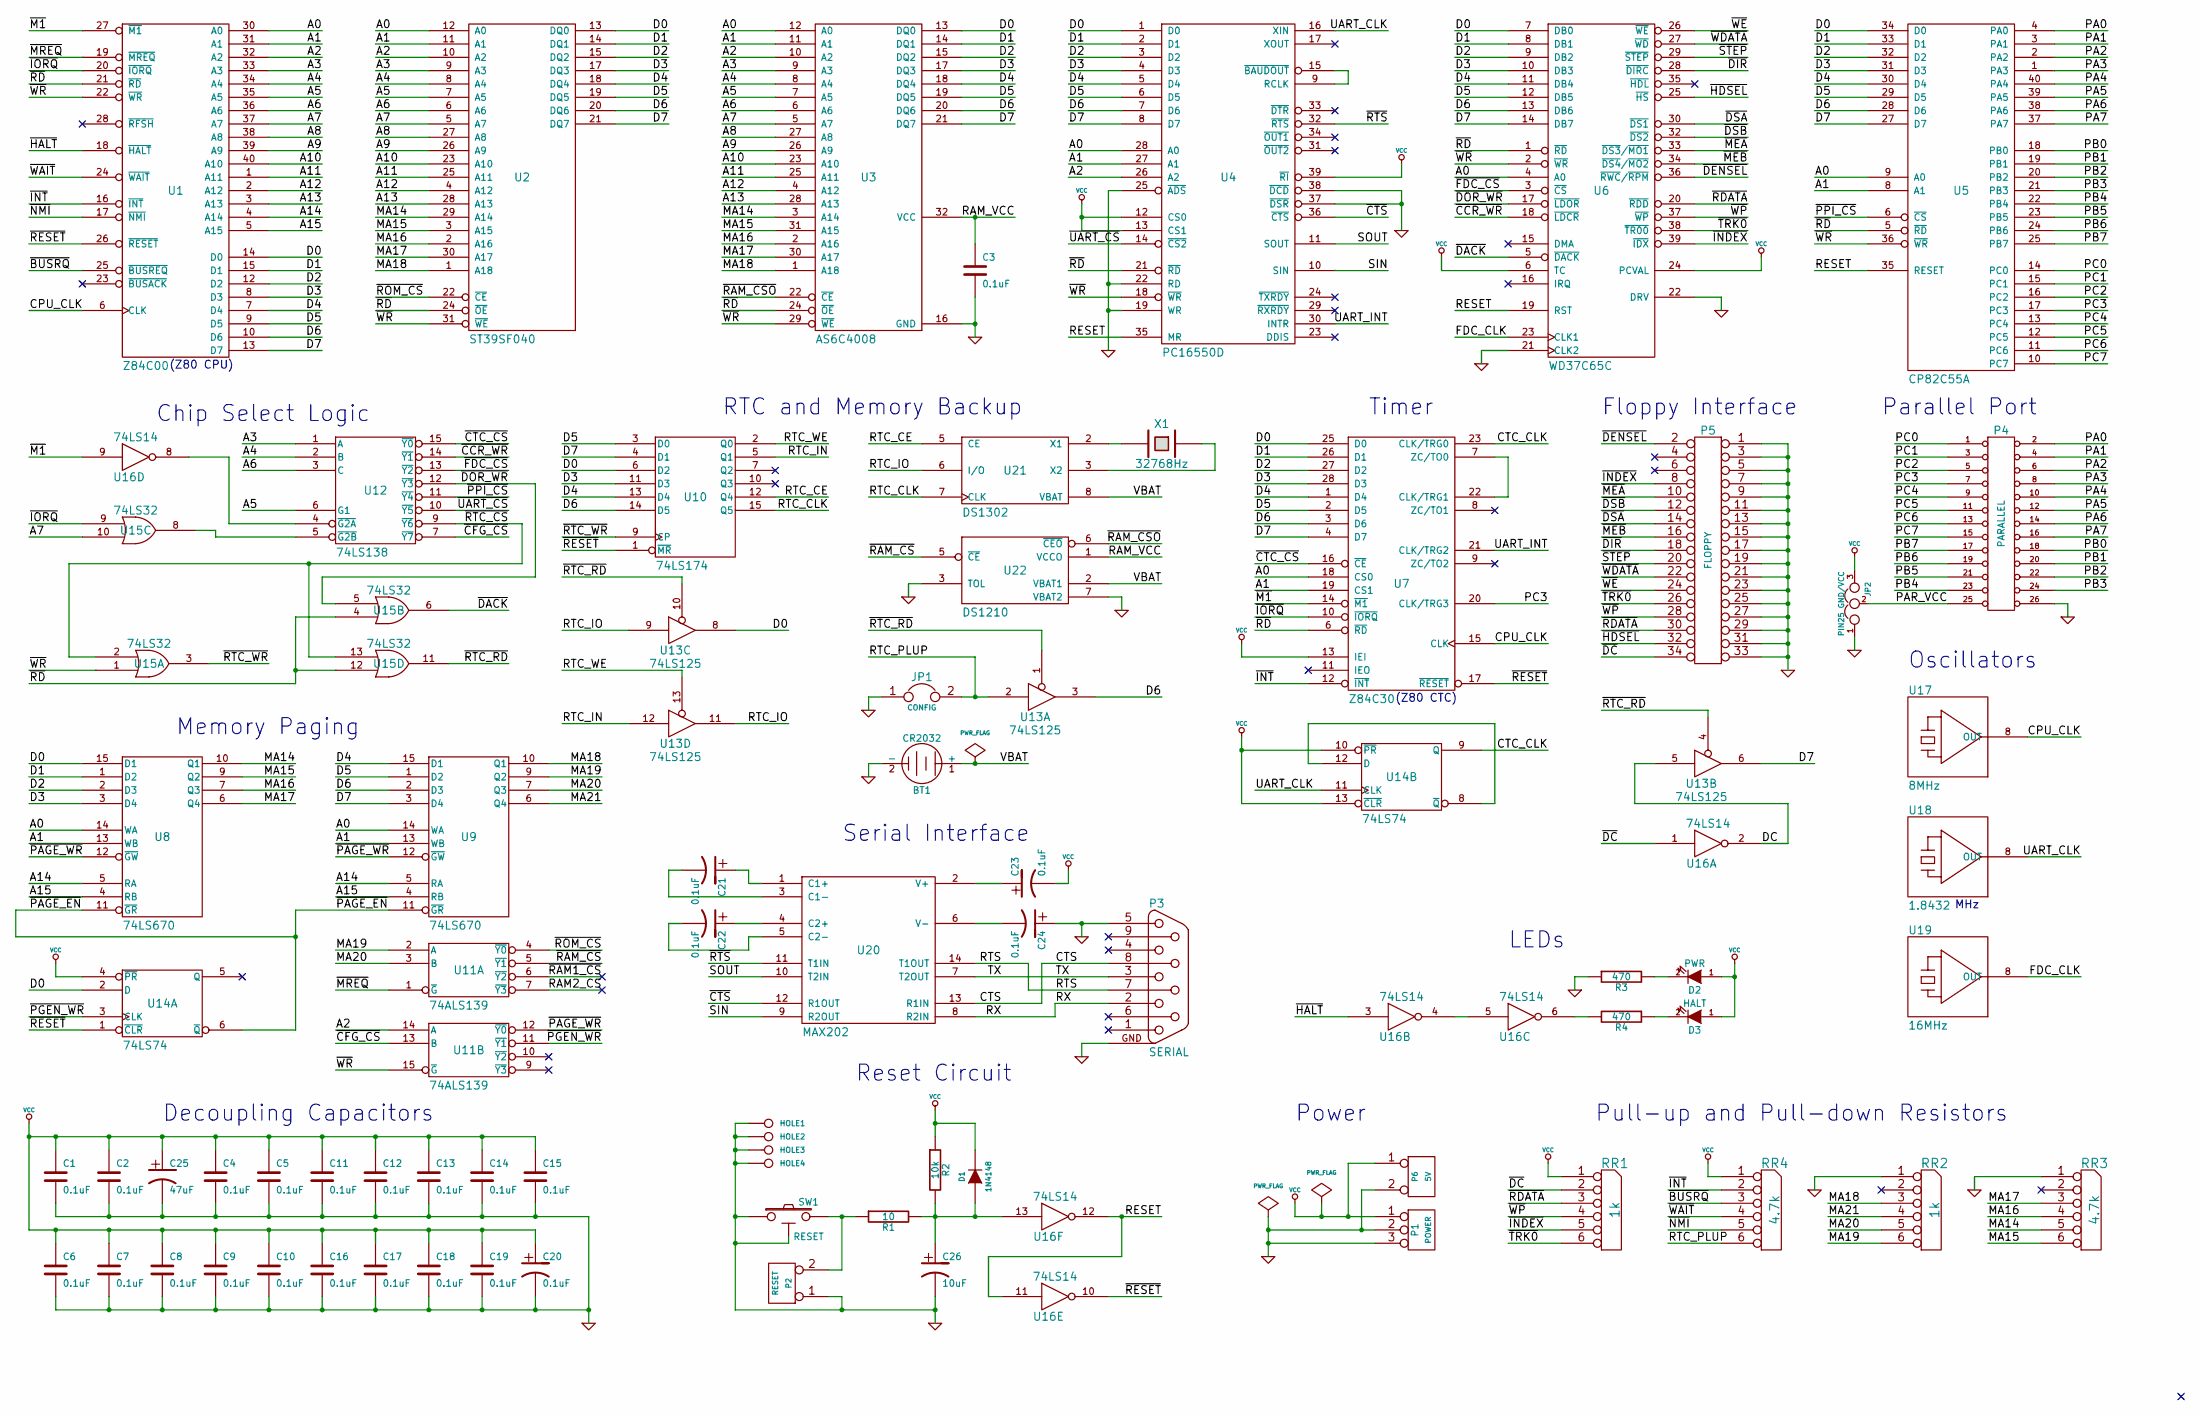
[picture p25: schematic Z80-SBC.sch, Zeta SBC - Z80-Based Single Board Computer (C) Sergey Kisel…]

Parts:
BT1: CR2032
C1, C2, C3, C4, C5, C6, C7, C8, C9, C10, C11, C12, C13, C14, C15, C16, C17, C18, C19, C20, C21, C22, C23, C24: 0.1uF
C25: 47uF
C26: 10uF
D1: 1N4148
D2: PWR
D3: HALT
HOLE1, HOLE2, HOLE3, HOLE4: CONN_1
JP1: CONFIG
JP2: PIN25 GND/VCC
P1: POWER
P2: RESET
P3: SERIAL
P4: PARALLEL
P5: FLOPPY
P6: 5V
R1: 10
R2: 10k
R3, R4: 470
RR1, RR2: 1k
RR3, RR4: 4.7k
SW1: RESET
U1: Z84C00
U2: ST39SF040
U3: AS6C4008
U4: PC16550D
U5: CP82C55A
U6: WD37C65C
U7: Z84C30
U8, U9: 74LS670
U10: 74LS174
U11: 74ALS139
U12: 74LS138
U13: 74LS125
U14: 74LS74
U15: 74LS32
U16: 74LS14
U17: 8MHz
U18: 1.8432
U19: 16MHz
U20: MAX202
U21: DS1302
U22: DS1210
X1: 32768Hz

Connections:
/A0: U1.30 (A0), U2.12 (A0), U3.12 (A0), U4.28 (A0), U5.9 (A0), U6.4 (A0), U7.18 (CS0), U8.14 (WA), U9.14 (WA)
/A1: U1.31 (A1), U2.11 (A1), U3.11 (A1), U4.27 (A1), U5.8 (A1), U7.19 (CS1), U8.13 (WB), U9.13 (WB)
/A2: U1.32 (A2), U2.10 (A2), U3.10 (A2), U4.26 (A2), U11.14 (A)
/A3: U1.33 (A3), U2.9 (A3), U3.9 (A3), U12.1 (A)
/A4: U1.34 (A4), U2.8 (A4), U3.8 (A4), U12.2 (B)
/A5: U1.35 (A5), U2.7 (A5), U3.7 (A5), U12.6 (G1)
/A6: U1.36 (A6), U2.6 (A6), U3.6 (A6), U12.3 (C)
/A7: U1.37 (A7), U2.5 (A7), U3.5 (A7), U15.10
/A8: U1.38 (A8), U2.27 (A8), U3.27 (A8)
/A9: U1.39 (A9), U2.26 (A9), U3.26 (A9)
/A10: U1.40 (A10), U2.23 (A10), U3.23 (A10)
/A11: U1.1 (A11), U2.25 (A11), U3.25 (A11)
/A12: U1.2 (A12), U2.4 (A12), U3.4 (A12)
/A13: U1.3 (A13), U2.28 (A13), U3.28 (A13)
/A14: U1.4 (A14), U8.5 (RA), U9.5 (RA)
/A15: U1.5 (A15), U8.4 (RB), U9.4 (RB)
/CPU_CLK: U1.6 (CLK), U7.15 (CLK), U17.8 (OUT)
/CTC_CLK: U7.23 (CLK/TRG0), U14.9 (Q)
/CTS: P3.8, U20.13 (R1IN)
/D0: U1.14 (D0), U2.13 (DQ0), U3.13 (DQ0), U4.1 (D0), U5.34 (D0), U6.7 (DB0), U7.25 (D0), U8.15 (D1), U10.6 (D2), U13.8, U14.2 (D)
/D1: U1.15 (D1), U2.14 (DQ1), U3.14 (DQ1), U4.2 (D1), U5.33 (D1), U6.8 (DB1), U7.26 (D1), U8.1 (D2)
/D2: U1.12 (D2), U2.15 (DQ2), U3.15 (DQ2), U4.3 (D2), U5.32 (D2), U6.9 (DB2), U7.27 (D2), U8.2 (D3)
/D3: U1.8 (D3), U2.17 (DQ3), U3.17 (DQ3), U4.4 (D3), U5.31 (D3), U6.10 (DB3), U7.28 (D3), U8.3 (D4), U10.11 (D3)
/D4: U1.7 (D4), U2.18 (DQ4), U3.18 (DQ4), U4.5 (D4), U5.30 (D4), U6.11 (DB4), U7.1 (D4), U9.15 (D1), U10.13 (D4)
/D5: U1.9 (D5), U2.19 (DQ5), U3.19 (DQ5), U4.6 (D5), U5.29 (D5), U6.12 (DB5), U7.2 (D5), U9.1 (D2), U10.3 (D0)
/D6: U1.10 (D6), U2.20 (DQ6), U3.20 (DQ6), U4.7 (D6), U5.28 (D6), U6.13 (DB6), U7.3 (D6), U9.2 (D3), U10.14 (D5), U13.3
/D7: U1.13 (D7), U2.21 (DQ7), U3.21 (DQ7), U4.8 (D7), U5.27 (D7), U6.14 (DB7), U7.4 (D7), U9.3 (D4), U10.4 (D1), U13.6
/DC: U13.5, U16.2
/FDC_CLK: U6.23 (CLK1), U19.8 (OUT)
/MA14: RR3.5, U2.29 (A14), U3.3 (A14), U8.10 (Q1)
/MA15: RR3.6, U2.3 (A15), U3.31 (A15), U8.9 (Q2)
/MA16: RR3.4, U2.2 (A16), U3.2 (A16), U8.7 (Q3)
/MA17: RR3.3, U2.30 (A17), U3.30 (A17), U8.6 (Q4)
/MA18: RR2.3, U2.1 (A18), U3.1 (A18), U9.10 (Q1)
/MA19: RR2.6, U9.9 (Q2), U11.2 (A)
/MA20: RR2.5, U9.7 (Q3), U11.3 (B)
/MA21: RR2.4, U9.6 (Q4)
/PA0: P4.2, U5.4 (PA0)
/PA1: P4.4, U5.3 (PA1)
/PA2: P4.6, U5.2 (PA2)
/PA3: P4.8, U5.1 (PA3)
/PA4: P4.10, U5.40 (PA4)
/PA5: P4.12, U5.39 (PA5)
/PA6: P4.14, U5.38 (PA6)
/PA7: P4.16, U5.37 (PA7)
/PAR_VCC: JP2.2, P4.25 (P24)
/PB0: P4.18, U5.18 (PB0)
/PB1: P4.20, U5.19 (PB1)
/PB2: P4.22, U5.20 (PB2)
/PB3: P4.24 (P20), U5.21 (PB3)
/PB4: P4.23, U5.22 (PB4)
/PB5: P4.21, U5.23 (PB5)
/PB6: P4.19, U5.24 (PB6)
/PB7: P4.17, U5.25 (PB7)
/PC0: P4.1, U5.14 (PC0)
/PC1: P4.3, U5.15 (PC1)
/PC2: P4.5, U5.16 (PC2)
/PC3: P4.7, U5.17 (PC3), U7.20 (CLK/TRG3)
/PC4: P4.9, U5.13 (PC4)
/PC5: P4.11, U5.12 (PC5)
/PC6: P4.13, U5.11 (PC6)
/PC7: P4.15, U5.10 (PC7)
/RAM_VCC: C3.1, U3.32 (VCC), U22.1 (VCCO)
/RESET: U4.35 (MR), U5.35 (RESET), U6.19 (RST), U16.11, U16.12
/RTC_CE: U10.12 (Q4), U21.5 (CE)
/RTC_CLK: U10.15 (Q5), U21.7 (CLK)
/RTC_IN: U10.5 (Q1), U13.12
/RTC_IO: U13.9, U13.11, U21.6 (I/O)
/RTC_PLUP: JP1.2, RR4.6, U13.2
/RTC_WE: U10.2 (Q0), U13.13
/RTS: P3.7, U20.14 (T1OUT)
/RX: P3.2, U20.8 (R2IN)
/SIN: U4.10 (SIN), U20.9 (R2OUT)
/SOUT: U4.11 (SOUT), U20.10 (T2IN)
/TX: P3.3, U20.7 (T2OUT)
/UART_CLK: U4.16 (XIN), U14.11 (CLK), U18.8 (OUT)
/UART_INT: U4.30 (INTR), U7.21 (CLK/TRG2)
/VBAT: BT1.1 (+), U21.8 (VBAT), U22.2 (VBAT1)
/~BUSRQ: RR4.3, U1.25 (~BUSREQ)
/~CCR_WR: U6.18 (~LDCR), U12.14 (~Y1)
/~CFG_CS: U11.13 (B), U12.7 (~Y7)
/~CTC_CS: U7.16 (~CE), U12.15 (~Y0)
/~CTS: U4.36 (~CTS), U20.12 (R1OUT)
/~DACK: U6.5 (~DACK), U15.6
/~DC: P5.34, RR1.2, U16.1
/~DENSEL: P5.2, U6.36 (~RWC~/~RPM~)
/~DIR: P5.18, U6.28 (~DIRC)
/~DOR_WR: U6.17 (~LDOR), U12.12 (~Y3), U15.5
/~DSA: P5.14, U6.30 (~DS1)
/~DSB: P5.12, U6.32 (~DS2)
/~FDC_CS: U6.3 (~CS), U12.13 (~Y2)
/~HALT: U1.18 (~HALT), U16.3
/~HDSEL: P5.32, U6.25 (~HS)
/~INDEX: P5.8, RR1.5, U6.39 (~IDX)
/~INT: RR4.2, U1.16 (~INT), U7.12 (~INT)
/~IORQ: U1.20 (~IORQ), U7.10 (~IORQ), U15.9
/~M1: U1.27 (~M1), U7.14 (~M1), U16.9
/~MEA: P5.10, U6.33 (~DS3~/~MO1~)
/~MEB: P5.16, U6.34 (~DS4~/~MO2~)
/~MREQ: U1.19 (~MREQ), U11.1 (~G)
/~NMI: RR4.5, U1.17 (~NMI)
/~PAGE_EN: U8.11 (~GR), U9.11 (~GR), U14.6 (~Q)
/~PAGE_WR: U8.12 (~GW), U9.12 (~GW), U11.12 (~Y0)
/~PGEN_WR: U11.11 (~Y1), U14.3 (CLK)
/~PPI_CS: U5.6 (~CS), U12.11 (~Y4)
/~RAM_CS: U11.5 (~Y1), U22.5 (~CE)
/~RAM_CSO: U3.22 (~CE), U22.6 (~CEO)
/~RD: U1.21 (~RD), U2.24 (~OE), U3.24 (~OE), U4.21 (~RD), U5.5 (~RD), U6.1 (~RD), U7.6 (~RD), U15.4, U15.12
/~RDATA: P5.30, RR1.3, U6.20 (~RDD)
/~RESET: U1.26 (~RESET), U7.17 (~RESET), U10.1 (~MR), U14.1 (~CLR), U16.10
/~ROM_CS: U2.22 (~CE), U11.4 (~Y0)
/~RTC_CS: U12.9 (~Y6), U15.2, U15.13
/~RTC_RD: U13.1, U13.4, U13.10, U15.11
/~RTC_WR: U10.9 (CP), U15.3
/~RTS: U4.32 (~RTS), U20.11 (T1IN)
/~STEP: P5.20, U6.29 (~STEP)
/~TRK0: P5.26, RR1.6, U6.38 (~TR00)
/~UART_CS: U4.14 (~CS2), U12.10 (~Y5)
/~WAIT: RR4.4, U1.24 (~WAIT)
/~WDATA: P5.22, U6.27 (~WD)
/~WE: P5.24, U6.26 (~WE)
/~WP: P5.28, RR1.4, U6.37 (~WP)
/~WR: U1.22 (~WR), U2.31 (~WE), U3.29 (~WE), U4.18 (~WR), U5.36 (~WR), U6.2 (~WR), U11.15 (~G), U15.1
GND: BT1.2 (-), C1.2, C2.2, C3.2, C4.2, C5.2, C6.2, C7.2, C8.2, C9.2, C10.2, C11.2, C12.2, C13.2, C14.2, C15.2, C16.2, C17.2, C18.2, C19.2, C20.2, C24.1, C25.2, C26.2, HOLE1.1, HOLE2.1, HOLE3.1, HOLE4.1, JP1.1, JP2.1, P1.2 (PM), P1.3, P2.1, P3.5, P3.GND, P4.26 (P22), P5.1, P5.3, P5.5, P5.7, P5.9, P5.11, P5.13, P5.15, P5.17, P5.19, P5.21, P5.23, P5.25, P5.27, P5.29, P5.31, P5.33, P6.2 (PM), R3.1, RR2.1 (COM), RR3.1 (COM), SW1.1, SW1.GND, U1.29 (GND), U2.16 (GND), U3.16 (GND), U4.19 (WR), U4.20 (GND), U4.22 (RD), U4.25 (~ADS), U4.37 (~DSR), U4.38 (~DCD), U5.7 (GND), U6.21 (CLK2), U6.22 (DRV), U6.31 (GND), U7.5 (GND), U8.8 (GND), U9.8 (GND), U10.8 (GND), U11.8 (GND), U12.8 (GND), U13.7 (GND), U14.7 (GND), U15.7 (GND), U16.7 (GND), U17.7 (GND), U18.7 (GND), U19.7 (GND), U20.15 (GND), U21.4 (GND), U22.3 (TOL), U22.4 (GND), U22.7 (VBAT2)
unnamed: C21.1, U20.1 (C1+)
unnamed: R4.2, U16.6
unnamed: C22.1, U20.4 (C2+)
unnamed: C23.1, U20.2 (V+)
unnamed: D3.2 (K), R4.1
unnamed: U12.4 (~G2A), U16.8
unnamed: U21.3 (X2), X1.1
unnamed: U4.9 (RCLK), U4.15 (~BAUDOUT)
unnamed: U21.2 (X1), X1.2
unnamed: P2.2 (PM), R1.1, SW1.2
unnamed: C26.1, D1.1 (A), R1.2, R2.2, U16.13
unnamed: U14.8 (~Q), U14.12 (D)
unnamed: D2.2 (K), R3.2
unnamed: U16.4, U16.5
unnamed: U7.7 (ZC/TO0), U7.22 (CLK/TRG1)
unnamed: C24.2, U20.6 (V-)
unnamed: C22.2, U20.5 (C2-)
unnamed: U12.5 (~G2B), U15.8
unnamed: C21.2, U20.3 (C1-)
VCC: C1.1, C2.1, C4.1, C5.1, C6.1, C7.1, C8.1, C9.1, C10.1, C11.1, C12.1, C13.1, C14.1, C15.1, C16.1, C17.1, C18.1, C19.1, C20.1, C23.2, C25.1, D1.2 (K), D2.1 (A), D3.1 (A), JP2.3, P1.1, P6.1, R2.1, RR1.1 (COM), RR4.1 (COM), U1.11 (VCC), U2.32 (VCC), U4.12 (CS0), U4.13 (CS1), U4.39 (~RI), U4.40 (VCC), U5.26 (VCC), U6.6 (TC), U6.24 (PCVAL), U6.40 (VCC), U7.13 (IEI), U7.24 (VCC), U8.16 (VCC), U9.16 (VCC), U10.16 (VCC), U11.16 (VCC), U12.16 (VCC), U13.14 (VCC), U14.4 (~PR), U14.10 (~PR), U14.13 (~CLR), U14.14 (VCC), U15.14 (VCC), U16.14 (VCC), U17.11 (VCC), U17.14 (VCC), U18.11 (VCC), U18.14 (VCC), U19.11 (VCC), U19.14 (VCC), U20.16 (VCC), U21.1 (VCC), U22.8 (VCC)

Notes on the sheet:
Pull-up and Pull-down Resistors
Power
Reset Circuit
LEDs
Parallel Port
Oscillators
Serial Interface
Floppy Interface
Decoupling Capacitors
RTC and Memory Backup
Chip Select Logic
Timer
Memory Paging
MHz
(Z80 CPU)
(Z80 CTC)

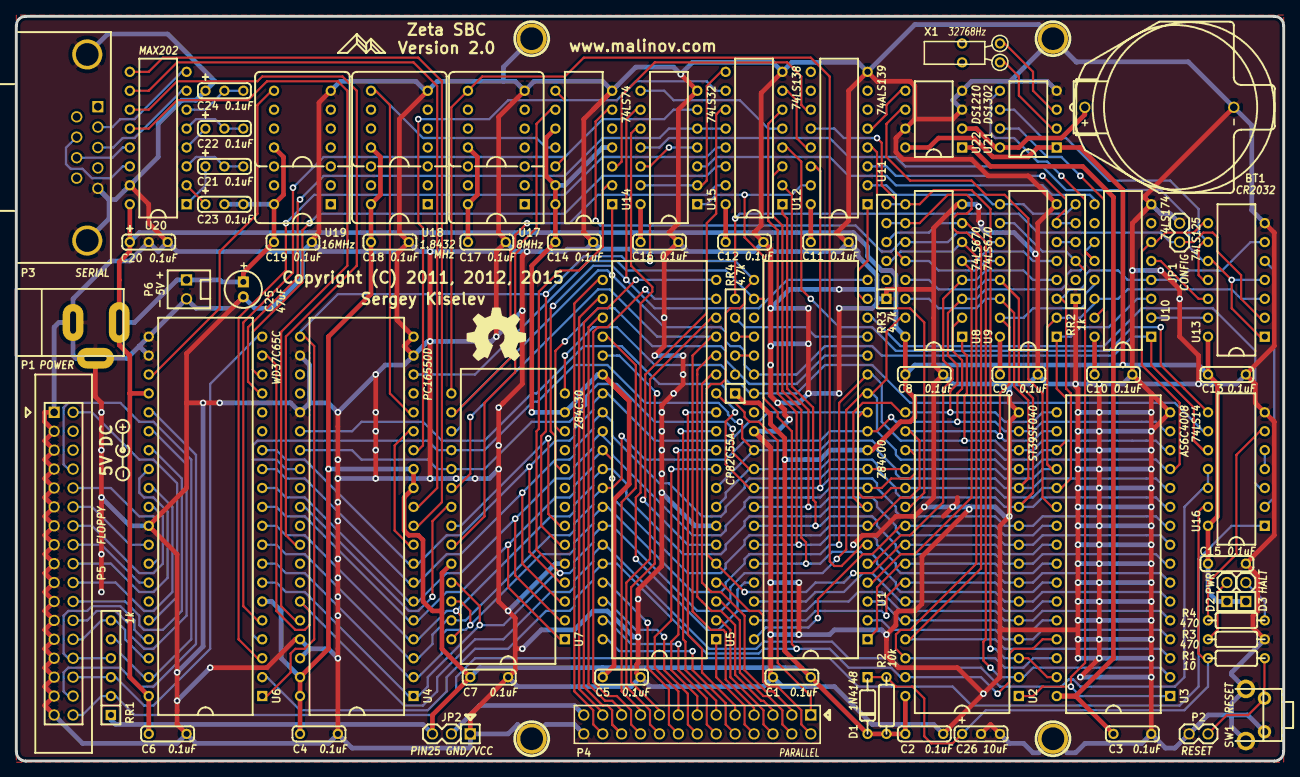
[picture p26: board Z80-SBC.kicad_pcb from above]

Board: 2 copper layers, 170.2 x 100.0 mm, 74 parts (0 on the bottom side), 144 nets.

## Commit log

2020-02-10 printed_parts: Add OpenSCAD and STL files
    [CaseGenerator-Zeta.scad, Zeta-Back.stl, Zeta-Bottom.stl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]
2020-02-11 printed_parts: Add photos
2020-02-11 printed_parts: Create README
2022-03-01 Add website materials, unpack the 1.3 gerber and KiCad directories from zip
    [Z80-SBC.brd, Z80-SBC.sch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]
2022-03-01 Add V2 website materials, unpack the 2.0 gerber and KiCad directories from zip
    [Z80-SBC-B_Mask.gbs, Z80-SBC-Back.gbl, Z80-SBC-Edge_Cuts.gbr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]
2023-10-27 Add links to KiCad design, schematic, and PCB files

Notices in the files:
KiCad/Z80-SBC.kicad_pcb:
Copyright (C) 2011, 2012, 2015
